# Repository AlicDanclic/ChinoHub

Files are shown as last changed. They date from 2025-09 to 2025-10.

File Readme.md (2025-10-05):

# ChinoHub

由于经常的插拔,导致我的电脑只有一个USB可以用来,是的只有一个了,所以我有必要做一个Hub,之前做一个支持2.0的KVM,但是突然有一个大电流以及没有做外壳导致这个hub由很大的问题,以及,该KVM的设计上仍有很多问题.例如大电流过滤问题,没有静电保护,同时该作为一个DIY项目,他似乎缺少了很多交互性,在参考了[TypeC转HDMI视频输出模块 - 立创开源硬件平台](https://oshwhub.com/lemon_wifi/CS5265)以及[高速USB3.0共享器 四进四出选择 HUB+切换器 - 立创开源硬件平台](https://oshwhub.com/aknice/vl822-ch484m-si-jin-si-chu-usb3-0-hub),我决定开启一个高速PCB的设计项目,ChinoHub,是的,我喜欢看点兔,我最喜欢智乃了❤.

## 项目架构

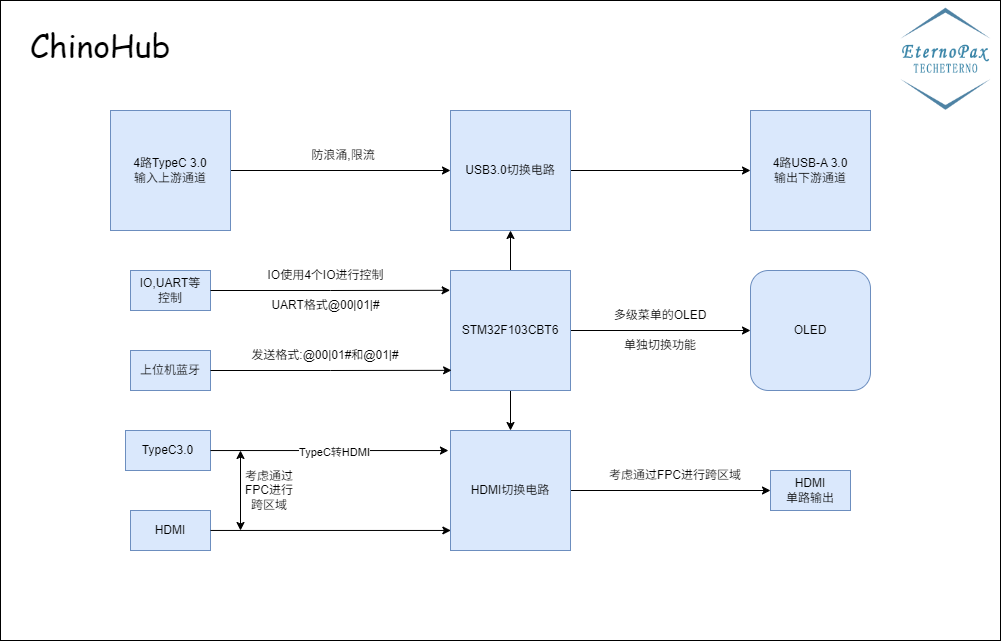
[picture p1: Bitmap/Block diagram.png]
系统框图


## 硬件设计注意事项

> 本设计大量用到USB3.0,布线时要遵循高速和差分.

在设计中,我们用到的电源为5V的输入,3.3V和1.0V的输入,(原理图中有1.8V那是芯片自己产生的,在本项目中没用),考虑最坏情况下,对应的峰值电流为:

| 电压域 | 最坏情况峰值电流 | 关键贡献者 |
| :--- | :--- | :--- |
| **3.3V** | **538 mA** | VL822(300mA) + CS5265(150mA) + STM32(75mA) |
| **5V** | **600 mA** | LP3220输入(400mA) + CS5265(200mA) |
| **1.0V** | **200 mA** | VL822(150mA) + CS5265(50mA) |

所以考虑1.5倍富裕度,这里选择了MP2122A,输出为2A的二路DCDC.同时STM32由LDO单独供电防止纹波问题.计算公式可以参看Datasheet,为:$0.6V \times(1+\frac{R_1}{R_2})$

在设计时候用了一个防浪涌的模拟电路,对于多电源可能同时输入,效果还是不错的.

## 软件烧录

## 使用指南

### 日志

2025.10.4完成原理图绘制,等待审查

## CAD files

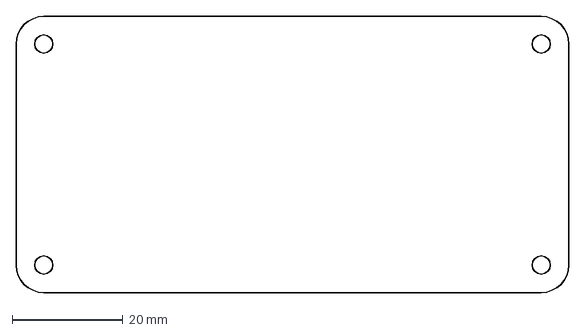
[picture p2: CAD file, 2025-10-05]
3D/plate_Cut.dxf
100.0 x 50.0 mm

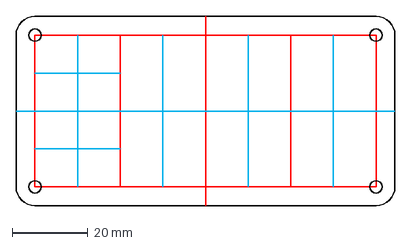
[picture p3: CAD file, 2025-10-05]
3D/plate.dxf
100.0 x 50.0 mm

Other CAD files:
3D/plate.dwg

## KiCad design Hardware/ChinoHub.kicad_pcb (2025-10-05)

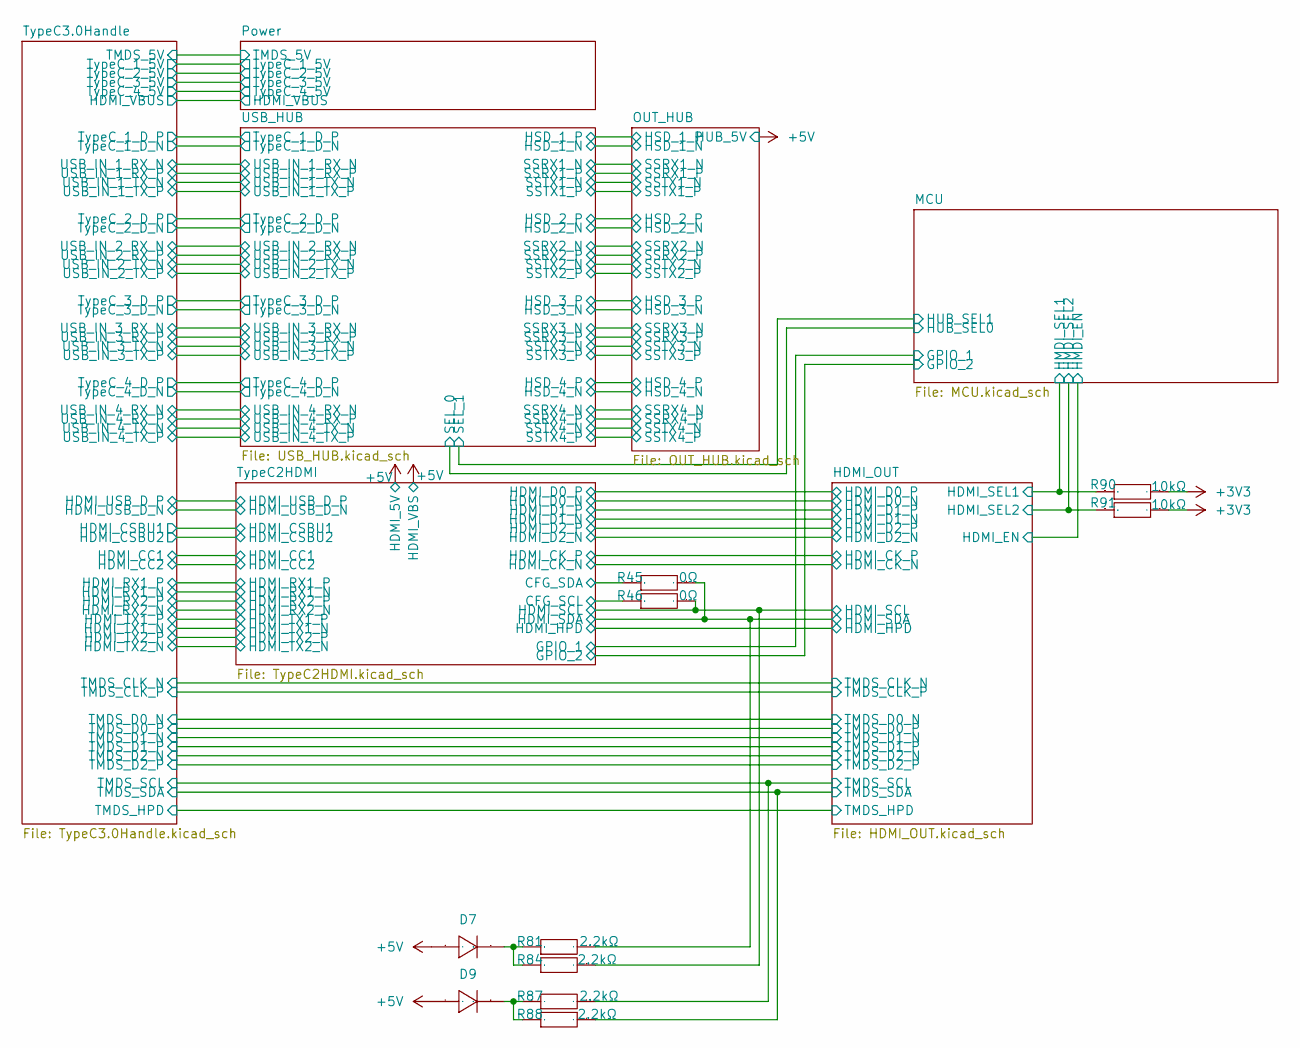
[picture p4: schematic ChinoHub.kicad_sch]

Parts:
D7, D9: SOD-323F_L1.7-W1.3-LS2.5-R-RD; Manufacturer Part 1N4148WSL; LCSC Part Name 1N4148WSL
R45, R46: 0Ω; R0603; Manufacturer Part 0603WAF1002T5E; LCSC Part Name 厚膜电阻 10kΩ ±1% 100mW
R81, R84, R87, R88: 2.2kΩ; R0603; Manufacturer Part 0603WAF1002T5E; LCSC Part Name 厚膜电阻 10kΩ ±1% 100mW
R90, R91: 10kΩ; R0603; Manufacturer Part 0603WAF1002T5E; LCSC Part Name 厚膜电阻 10kΩ ±1% 100mW

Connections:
+3V3: R90.2, R91.2; also elsewhere on the board
+5V: D7.2, D9.2; also elsewhere on the board
/HDMI_OUT/HDMI_SCL: R46.2, R84.2; also elsewhere on the board
/HDMI_OUT/HDMI_SDA: R45.2, R81.2; also elsewhere on the board
/HDMI_OUT/TMDS_SCL: R87.2; also elsewhere on the board
/HDMI_OUT/TMDS_SDA: R88.2; also elsewhere on the board
/MCU/HDMI_SEL1: R90.1; also elsewhere on the board
/MCU/HDMI_SEL2: R91.1; also elsewhere on the board
/TypeC2HDMI/CFG_SCL: R46.1; also elsewhere on the board
/TypeC2HDMI/CFG_SDA: R45.1; also elsewhere on the board
unnamed: D7.1, R81.1, R84.1
unnamed: D9.1, R87.1, R88.1

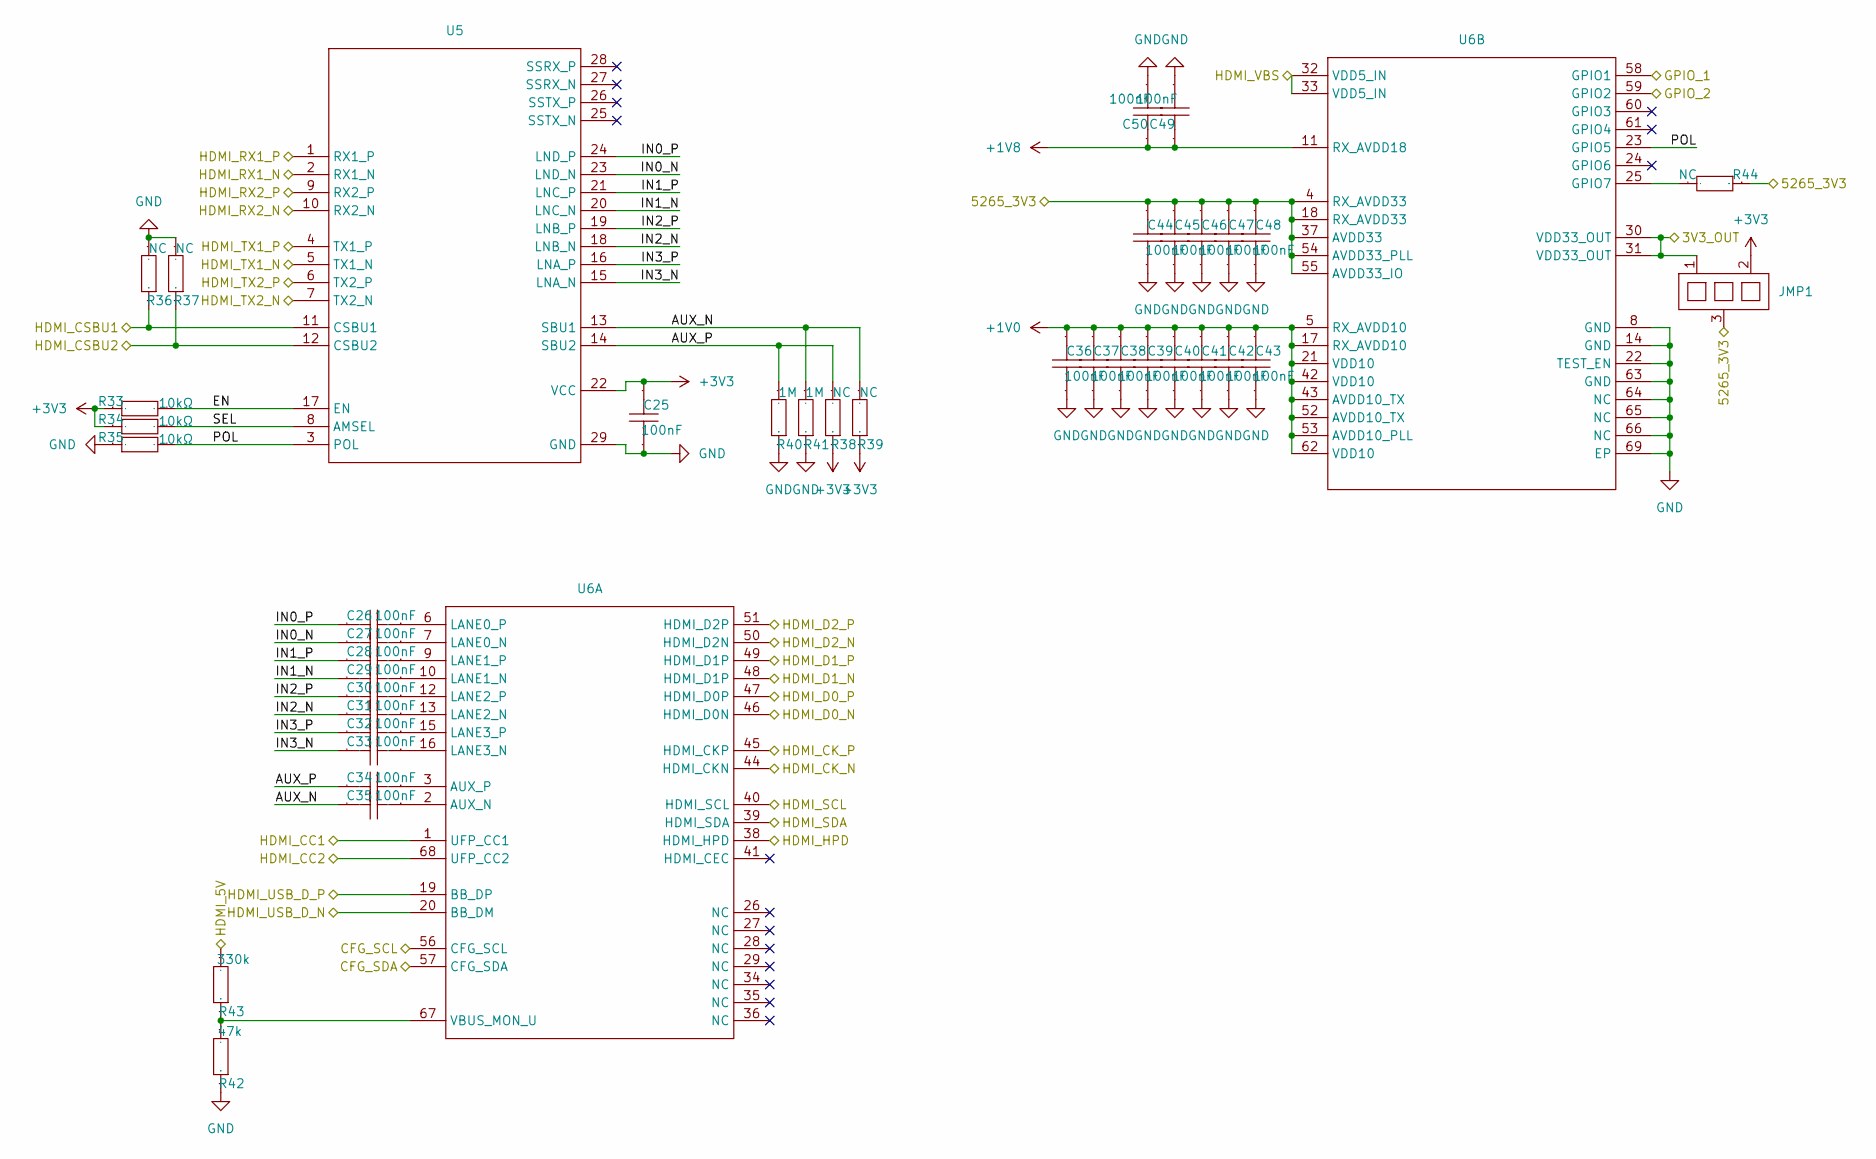
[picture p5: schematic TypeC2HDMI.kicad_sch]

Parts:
C25, C26, C27, C28, C29, C30, C31, C32, C33, C34, C35, C36, C37, C38, C39, C40, C41, C42, C43, C44, C45, C46, C47, C48, C49, C50: 100nF; C0603; Manufacturer Part CL10A105KB8NNNC; LCSC Part Name 1uF ±10% 50V
JMP1: JUMP0603
R33, R34, R35: 10kΩ; R0603; Manufacturer Part 0603WAF1002T5E; LCSC Part Name 厚膜电阻 10kΩ ±1% 100mW
R36, R37, R38, R39, R44: NC; R0603; Manufacturer Part 0603WAF1002T5E; LCSC Part Name 厚膜电阻 10kΩ ±1% 100mW
R40, R41: 1M; R0603; Manufacturer Part 0603WAF1002T5E; LCSC Part Name 厚膜电阻 10kΩ ±1% 100mW
R42: 47k; R0603; Manufacturer Part 0603WAF1002T5E; LCSC Part Name 厚膜电阻 10kΩ ±1% 100mW
R43: 330k; R0603; Manufacturer Part 0603WAF1002T5E; LCSC Part Name 厚膜电阻 10kΩ ±1% 100mW
U5: MQFN-28_L4.5-W3.5-P0.40-BL-EP
U6: QFN-68

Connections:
+1V0: C36.2, C37.2, C38.2, C39.2, C40.2, C41.2, C42.2, C43.2, U6.5 (RX_AVDD10), U6.17 (RX_AVDD10), U6.21 (VDD10), U6.42 (VDD10), U6.43 (AVDD10_TX), U6.52 (AVDD10_TX), U6.53 (AVDD10_PLL), U6.62 (VDD10); also elsewhere on the board
+1V8: C49.2, C50.2, U6.11 (RX_AVDD18)
+3V3: C25.2, JMP1.2, R33.1, R34.1, R38.1, R39.1, U5.22 (VCC); also elsewhere on the board
+5V: R43.2, U6.32 (VDD5_IN), U6.33 (VDD5_IN); also elsewhere on the board
/HDMI_OUT/HDMI_CK_N: U6.44 (HDMI_CKN); also elsewhere on the board
/HDMI_OUT/HDMI_CK_P: U6.45 (HDMI_CKP); also elsewhere on the board
/HDMI_OUT/HDMI_D0_N: U6.46 (HDMI_D0N); also elsewhere on the board
/HDMI_OUT/HDMI_D0_P: U6.47 (HDMI_D0P); also elsewhere on the board
/HDMI_OUT/HDMI_D1_N: U6.48 (HDMI_D1P); also elsewhere on the board
/HDMI_OUT/HDMI_D1_P: U6.49 (HDMI_D1P); also elsewhere on the board
/HDMI_OUT/HDMI_D2_N: U6.50 (HDMI_D2N); also elsewhere on the board
/HDMI_OUT/HDMI_D2_P: U6.51 (HDMI_D2P); also elsewhere on the board
/HDMI_OUT/HDMI_HPD: U6.38 (HDMI_HPD); also elsewhere on the board
/HDMI_OUT/HDMI_SCL: U6.40 (HDMI_SCL); also elsewhere on the board
/HDMI_OUT/HDMI_SDA: U6.39 (HDMI_SDA); also elsewhere on the board
/MCU/GPIO_1: U6.58 (GPIO1); also elsewhere on the board
/MCU/GPIO_2: U6.59 (GPIO2); also elsewhere on the board
/TypeC2HDMI/3V3_OUT: JMP1.1, U6.30 (VDD33_OUT), U6.31 (VDD33_OUT)
/TypeC2HDMI/5265_3V3: C44.2, C45.2, C46.2, C47.2, C48.2, JMP1.3, R44.1, U6.4 (RX_AVDD33), U6.18 (RX_AVDD33), U6.37 (AVDD33), U6.54 (AVDD33_PLL), U6.55 (AVDD33_IO)
/TypeC2HDMI/AUX_N: C35.2, R39.2, R41.2, U5.13 (SBU1)
/TypeC2HDMI/AUX_P: C34.2, R38.2, R40.2, U5.14 (SBU2)
/TypeC2HDMI/CFG_SCL: U6.56 (CFG_SCL); also elsewhere on the board
/TypeC2HDMI/CFG_SDA: U6.57 (CFG_SDA); also elsewhere on the board
/TypeC2HDMI/EN: R33.2, U5.17 (EN)
/TypeC2HDMI/HDMI_CC1: U6.1 (UFP_CC1); also elsewhere on the board
/TypeC2HDMI/HDMI_CC2: U6.68 (UFP_CC2); also elsewhere on the board
/TypeC2HDMI/HDMI_CSBU1: R36.1, U5.11 (CSBU1); also elsewhere on the board
/TypeC2HDMI/HDMI_CSBU2: R37.1, U5.12 (CSBU2); also elsewhere on the board
/TypeC2HDMI/HDMI_RX1_N: U5.2 (RX1_N); also elsewhere on the board
/TypeC2HDMI/HDMI_RX1_P: U5.1 (RX1_P); also elsewhere on the board
/TypeC2HDMI/HDMI_RX2_N: U5.10 (RX2_N); also elsewhere on the board
/TypeC2HDMI/HDMI_RX2_P: U5.9 (RX2_P); also elsewhere on the board
/TypeC2HDMI/HDMI_TX1_N: U5.5 (TX1_N); also elsewhere on the board
/TypeC2HDMI/HDMI_TX1_P: U5.4 (TX1_P); also elsewhere on the board
/TypeC2HDMI/HDMI_TX2_N: U5.7 (TX2_N); also elsewhere on the board
/TypeC2HDMI/HDMI_TX2_P: U5.6 (TX2_P); also elsewhere on the board
/TypeC2HDMI/HDMI_USB_D_N: U6.20 (BB_DM); also elsewhere on the board
/TypeC2HDMI/HDMI_USB_D_P: U6.19 (BB_DP); also elsewhere on the board
/TypeC2HDMI/IN0_N: C27.2, U5.23 (LND_N)
/TypeC2HDMI/IN0_P: C26.2, U5.24 (LND_P)
/TypeC2HDMI/IN1_N: C29.2, U5.20 (LNC_N)
/TypeC2HDMI/IN1_P: C28.2, U5.21 (LNC_P)
/TypeC2HDMI/IN2_N: C31.2, U5.18 (LNB_N)
/TypeC2HDMI/IN2_P: C30.2, U5.19 (LNB_P)
/TypeC2HDMI/IN3_N: C33.2, U5.15 (LNA_N)
/TypeC2HDMI/IN3_P: C32.2, U5.16 (LNA_P)
/TypeC2HDMI/POL: R35.2, U5.3 (POL), U6.23 (GPIO5)
/TypeC2HDMI/SEL: R34.2, U5.8 (AMSEL)
GND: C25.1, C36.1, C37.1, C38.1, C39.1, C40.1, C41.1, C42.1, C43.1, C44.1, C45.1, C46.1, C47.1, C48.1, C49.1, C50.1, R35.1, R36.2, R37.2, R40.1, R41.1, R42.1, U5.29 (GND), U6.8 (GND), U6.14 (GND), U6.22 (TEST_EN), U6.63 (GND), U6.64 (NC), U6.65 (NC), U6.66 (NC), U6.69 (EP); also elsewhere on the board
unnamed: C35.1, U6.2 (AUX_N)
unnamed: C34.1, U6.3 (AUX_P)
unnamed: C27.1, U6.7 (LANE0_N)
unnamed: C26.1, U6.6 (LANE0_P)
unnamed: C29.1, U6.10 (LANE1_N)
unnamed: C28.1, U6.9 (LANE1_P)
unnamed: C31.1, U6.13 (LANE2_N)
unnamed: C30.1, U6.12 (LANE2_P)
unnamed: C33.1, U6.16 (LANE3_N)
unnamed: C32.1, U6.15 (LANE3_P)
unnamed: R42.2, R43.1, U6.67 (VBUS_MON_U)
unnamed: R44.2, U6.25 (GPIO7)

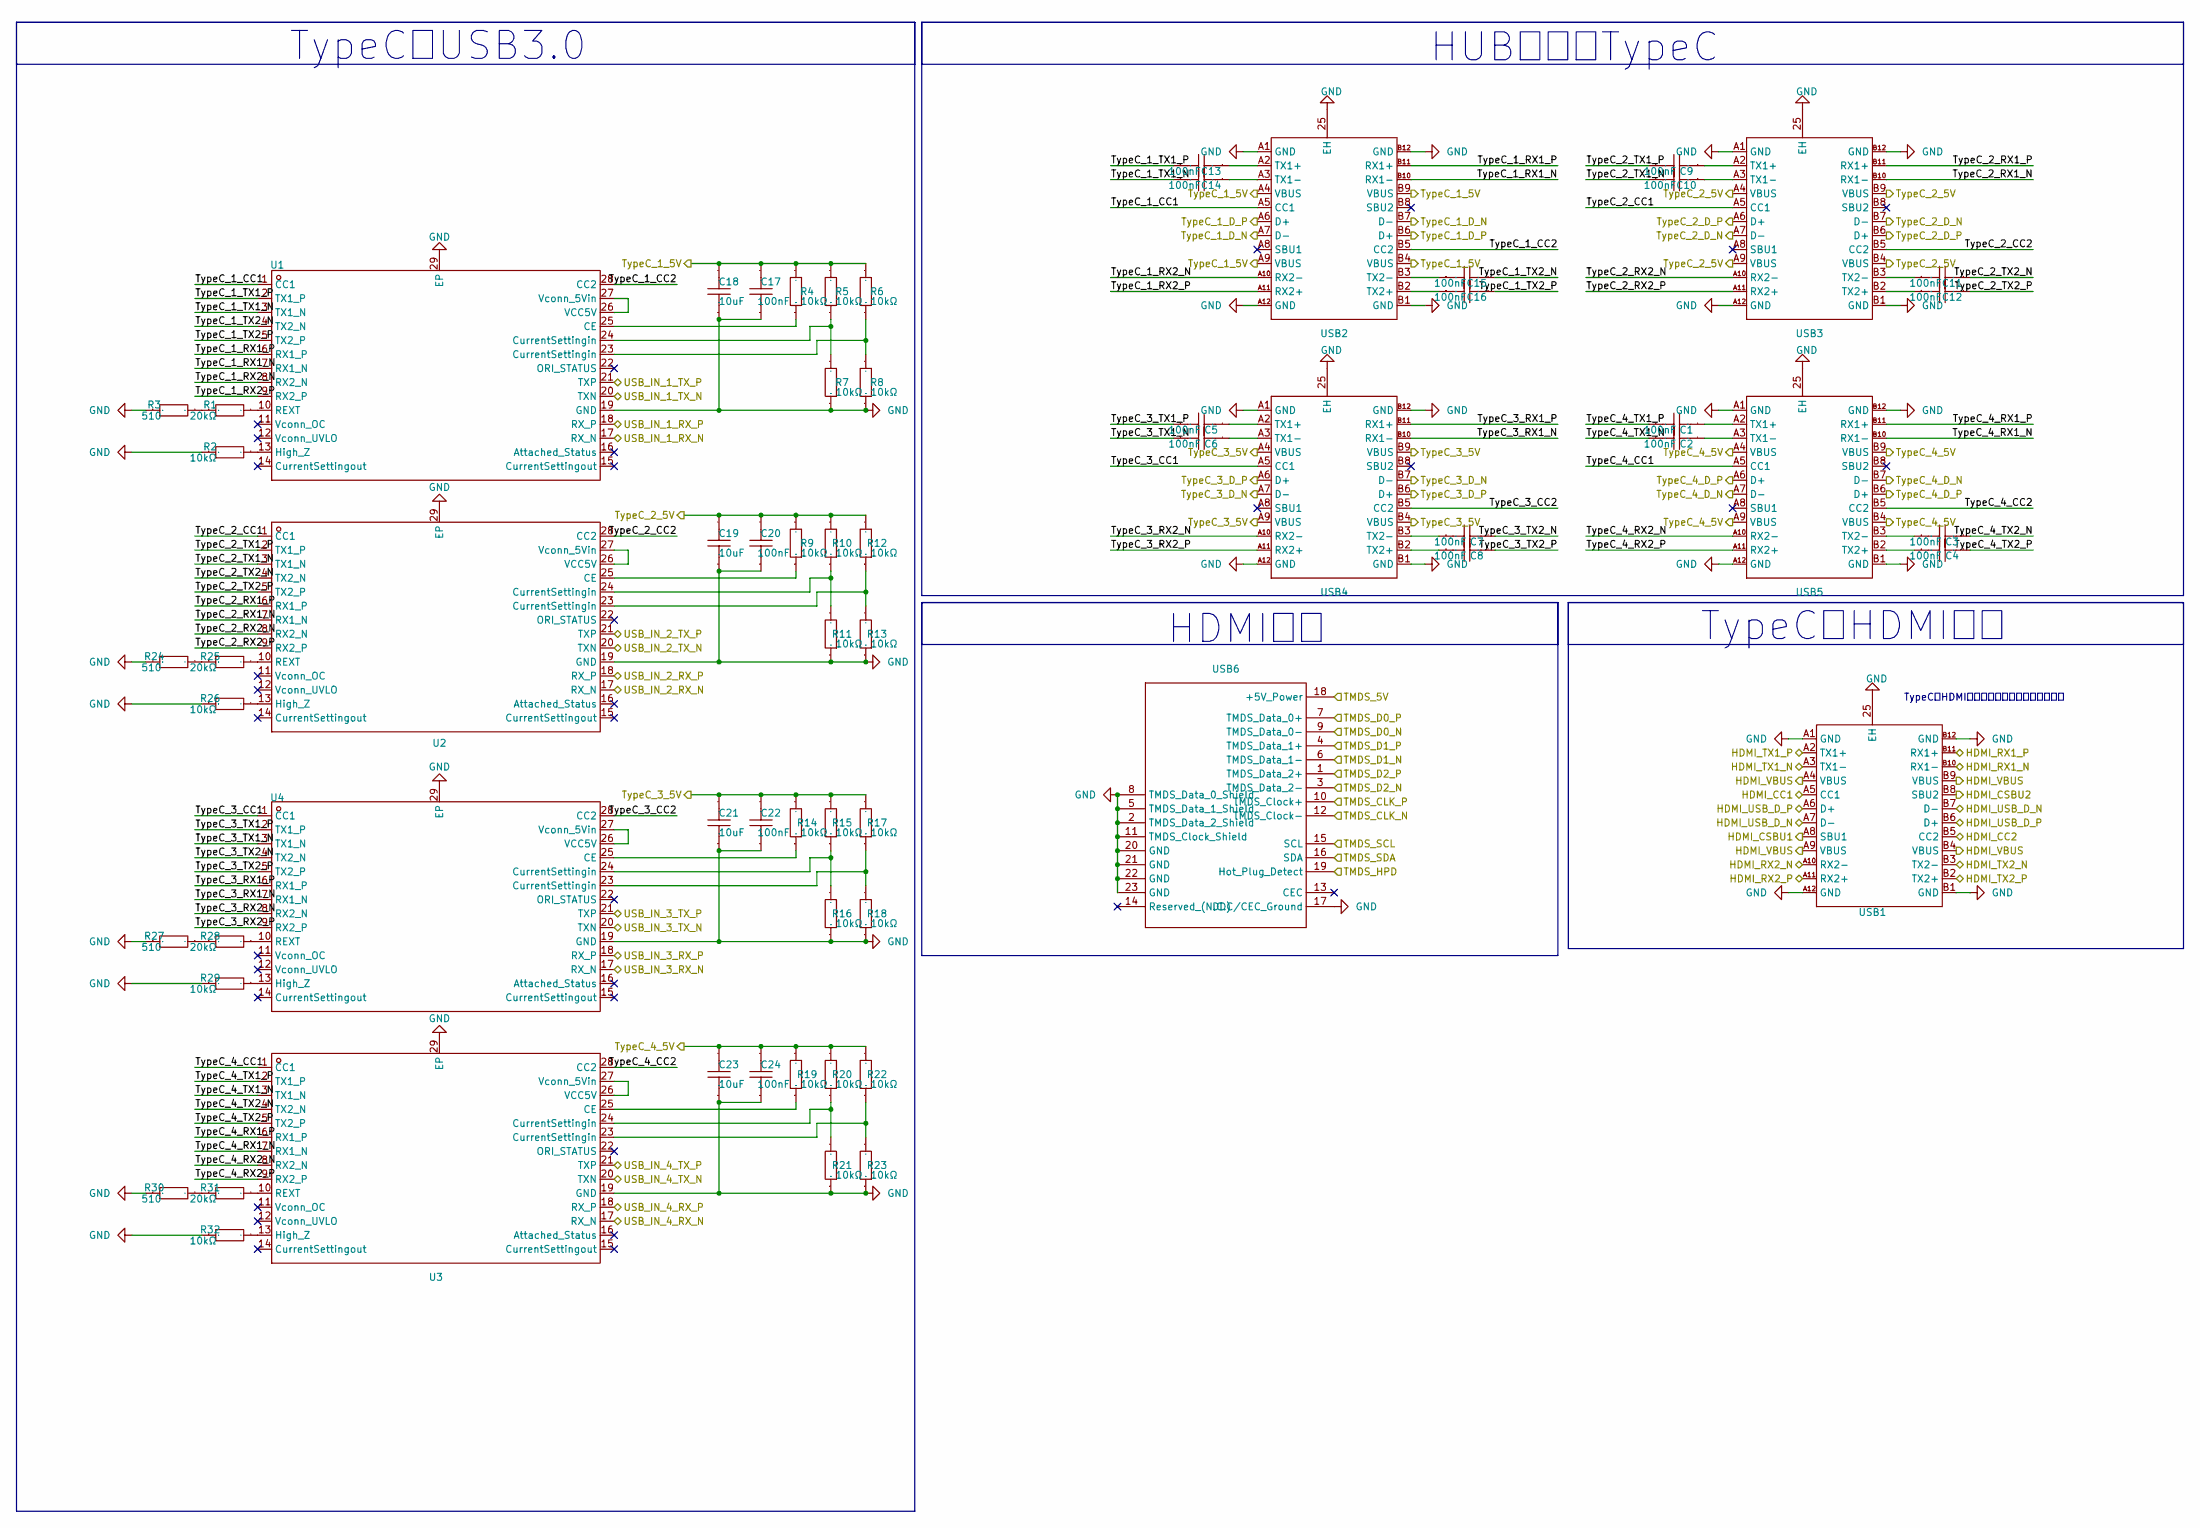
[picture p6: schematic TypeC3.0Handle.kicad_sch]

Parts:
C1, C2, C3, C4, C5, C6, C7, C8, C9, C10, C11, C12, C13, C14, C15, C16, C17, C20, C22, C24: 100nF; C0603; Manufacturer Part CL10A105KB8NNNC; LCSC Part Name 1uF ±10% 50V
C18, C19, C21, C23: 10uF; C0603; Manufacturer Part CL10A105KB8NNNC; LCSC Part Name 1uF ±10% 50V
R1, R25, R28, R31: 20kΩ; R0603; Manufacturer Part 0603WAF1002T5E; LCSC Part Name 厚膜电阻 10kΩ ±1% 100mW
R2, R4, R5, R6, R7, R8, R9, R10, R11, R12, R13, R14, R15, R16, R17, R18, R19, R20, R21, R22, R23, R26, R29, R32: 10kΩ; R0603; Manufacturer Part 0603WAF1002T5E; LCSC Part Name 厚膜电阻 10kΩ ±1% 100mW
R3, R24, R27, R30: 510; R0603; Manufacturer Part 0603WAF1002T5E; LCSC Part Name 厚膜电阻 10kΩ ±1% 100mW
U1, U2, U3, U4: MQFN-28_L4.5-W3.5-P0.40-BL-EP; Manufacturer Part VL160; LCSC Part Name VL160
USB1, USB2, USB3, USB4, USB5: TYPE-C-SMD_TYPE-C-24P-QCHT; Manufacturer Part TYPE-C 24P QCHT; LCSC Part Name Type-C 母 卧贴
USB6: HDMI-SMD_HDMI-001S; Manufacturer Part HDMI-001S; LCSC Part Name HDMI-001S

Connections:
/HDMI_OUT/TMDS_CLK_N: USB6.12 (TMDS_Clock-); also elsewhere on the board
/HDMI_OUT/TMDS_CLK_P: USB6.10 (TMDS_Clock+); also elsewhere on the board
/HDMI_OUT/TMDS_D0_N: USB6.9 (TMDS_Data_0-); also elsewhere on the board
/HDMI_OUT/TMDS_D0_P: USB6.7 (TMDS_Data_0+); also elsewhere on the board
/HDMI_OUT/TMDS_D1_N: USB6.6 (TMDS_Data_1-); also elsewhere on the board
/HDMI_OUT/TMDS_D1_P: USB6.4 (TMDS_Data_1+); also elsewhere on the board
/HDMI_OUT/TMDS_D2_N: USB6.3 (TMDS_Data_2-); also elsewhere on the board
/HDMI_OUT/TMDS_D2_P: USB6.1 (TMDS_Data_2+); also elsewhere on the board
/HDMI_OUT/TMDS_HPD: USB6.19 (Hot_Plug_Detect); also elsewhere on the board
/HDMI_OUT/TMDS_SCL: USB6.15 (SCL); also elsewhere on the board
/HDMI_OUT/TMDS_SDA: USB6.16 (SDA); also elsewhere on the board
/Power/HDMI_VBUS: USB1.A4 (VBUS), USB1.A9 (VBUS), USB1.B4 (VBUS), USB1.B9 (VBUS); also elsewhere on the board
/Power/TMDS_5V: USB6.18 (+5V_Power); also elsewhere on the board
/Power/TypeC_1_5V: C17.2, C18.2, R4.2, R5.2, R6.2, USB2.A4 (VBUS), USB2.A9 (VBUS), USB2.B4 (VBUS), USB2.B9 (VBUS); also elsewhere on the board
/Power/TypeC_2_5V: C19.2, C20.2, R9.2, R10.2, R12.2, USB3.A4 (VBUS), USB3.A9 (VBUS), USB3.B4 (VBUS), USB3.B9 (VBUS); also elsewhere on the board
/Power/TypeC_3_5V: C21.2, C22.2, R14.2, R15.2, R17.2, USB4.A4 (VBUS), USB4.A9 (VBUS), USB4.B4 (VBUS), USB4.B9 (VBUS); also elsewhere on the board
/Power/TypeC_4_5V: C23.2, C24.2, R19.2, R20.2, R22.2, USB5.A4 (VBUS), USB5.A9 (VBUS), USB5.B4 (VBUS), USB5.B9 (VBUS); also elsewhere on the board
/TypeC2HDMI/HDMI_CC1: USB1.A5 (CC1); also elsewhere on the board
/TypeC2HDMI/HDMI_CC2: USB1.B5 (CC2); also elsewhere on the board
/TypeC2HDMI/HDMI_CSBU1: USB1.A8 (SBU1); also elsewhere on the board
/TypeC2HDMI/HDMI_CSBU2: USB1.B8 (SBU2); also elsewhere on the board
/TypeC2HDMI/HDMI_RX1_N: USB1.B10 (RX1-); also elsewhere on the board
/TypeC2HDMI/HDMI_RX1_P: USB1.B11 (RX1+); also elsewhere on the board
/TypeC2HDMI/HDMI_RX2_N: USB1.A10 (RX2-); also elsewhere on the board
/TypeC2HDMI/HDMI_RX2_P: USB1.A11 (RX2+); also elsewhere on the board
/TypeC2HDMI/HDMI_TX1_N: USB1.A3 (TX1-); also elsewhere on the board
/TypeC2HDMI/HDMI_TX1_P: USB1.A2 (TX1+); also elsewhere on the board
/TypeC2HDMI/HDMI_TX2_N: USB1.B3 (TX2-); also elsewhere on the board
/TypeC2HDMI/HDMI_TX2_P: USB1.B2 (TX2+); also elsewhere on the board
/TypeC2HDMI/HDMI_USB_D_N: USB1.A7 (D-), USB1.B7 (D-); also elsewhere on the board
/TypeC2HDMI/HDMI_USB_D_P: USB1.A6 (D+), USB1.B6 (D+); also elsewhere on the board
/TypeC3.0Handle/TypeC_1_CC1: U1.1 (CC1), USB2.A5 (CC1)
/TypeC3.0Handle/TypeC_1_CC2: U1.28 (CC2), USB2.B5 (CC2)
/TypeC3.0Handle/TypeC_1_D_N: USB2.A7 (D-), USB2.B7 (D-); also elsewhere on the board
/TypeC3.0Handle/TypeC_1_D_P: USB2.A6 (D+), USB2.B6 (D+); also elsewhere on the board
/TypeC3.0Handle/TypeC_1_RX1_N: U1.7 (RX1_N), USB2.B10 (RX1-)
/TypeC3.0Handle/TypeC_1_RX1_P: U1.6 (RX1_P), USB2.B11 (RX1+)
/TypeC3.0Handle/TypeC_1_RX2_N: U1.8 (RX2_N), USB2.A10 (RX2-)
/TypeC3.0Handle/TypeC_1_RX2_P: U1.9 (RX2_P), USB2.A11 (RX2+)
/TypeC3.0Handle/TypeC_1_TX1_N: C14.1, U1.3 (TX1_N)
/TypeC3.0Handle/TypeC_1_TX1_P: C13.1, U1.2 (TX1_P)
/TypeC3.0Handle/TypeC_1_TX2_N: C15.2, U1.4 (TX2_N)
/TypeC3.0Handle/TypeC_1_TX2_P: C16.2, U1.5 (TX2_P)
/TypeC3.0Handle/TypeC_2_CC1: U2.1 (CC1), USB3.A5 (CC1)
/TypeC3.0Handle/TypeC_2_CC2: U2.28 (CC2), USB3.B5 (CC2)
/TypeC3.0Handle/TypeC_2_D_N: USB3.A7 (D-), USB3.B7 (D-); also elsewhere on the board
/TypeC3.0Handle/TypeC_2_D_P: USB3.A6 (D+), USB3.B6 (D+); also elsewhere on the board
/TypeC3.0Handle/TypeC_2_RX1_N: U2.7 (RX1_N), USB3.B10 (RX1-)
/TypeC3.0Handle/TypeC_2_RX1_P: U2.6 (RX1_P), USB3.B11 (RX1+)
/TypeC3.0Handle/TypeC_2_RX2_N: U2.8 (RX2_N), USB3.A10 (RX2-)
/TypeC3.0Handle/TypeC_2_RX2_P: U2.9 (RX2_P), USB3.A11 (RX2+)
/TypeC3.0Handle/TypeC_2_TX1_N: C10.1, U2.3 (TX1_N)
/TypeC3.0Handle/TypeC_2_TX1_P: C9.1, U2.2 (TX1_P)
/TypeC3.0Handle/TypeC_2_TX2_N: C11.2, U2.4 (TX2_N)
/TypeC3.0Handle/TypeC_2_TX2_P: C12.2, U2.5 (TX2_P)
/TypeC3.0Handle/TypeC_3_CC1: U4.1 (CC1), USB4.A5 (CC1)
/TypeC3.0Handle/TypeC_3_CC2: U4.28 (CC2), USB4.B5 (CC2)
/TypeC3.0Handle/TypeC_3_D_N: USB4.A7 (D-), USB4.B7 (D-); also elsewhere on the board
/TypeC3.0Handle/TypeC_3_D_P: USB4.A6 (D+), USB4.B6 (D+); also elsewhere on the board
/TypeC3.0Handle/TypeC_3_RX1_N: U4.7 (RX1_N), USB4.B10 (RX1-)
/TypeC3.0Handle/TypeC_3_RX1_P: U4.6 (RX1_P), USB4.B11 (RX1+)
/TypeC3.0Handle/TypeC_3_RX2_N: U4.8 (RX2_N), USB4.A10 (RX2-)
/TypeC3.0Handle/TypeC_3_RX2_P: U4.9 (RX2_P), USB4.A11 (RX2+)
/TypeC3.0Handle/TypeC_3_TX1_N: C6.1, U4.3 (TX1_N)
/TypeC3.0Handle/TypeC_3_TX1_P: C5.1, U4.2 (TX1_P)
/TypeC3.0Handle/TypeC_3_TX2_N: C7.2, U4.4 (TX2_N)
/TypeC3.0Handle/TypeC_3_TX2_P: C8.2, U4.5 (TX2_P)
/TypeC3.0Handle/TypeC_4_CC1: U3.1 (CC1), USB5.A5 (CC1)
/TypeC3.0Handle/TypeC_4_CC2: U3.28 (CC2), USB5.B5 (CC2)
/TypeC3.0Handle/TypeC_4_D_N: USB5.A7 (D-), USB5.B7 (D-); also elsewhere on the board
/TypeC3.0Handle/TypeC_4_D_P: USB5.A6 (D+), USB5.B6 (D+); also elsewhere on the board
/TypeC3.0Handle/TypeC_4_RX1_N: U3.7 (RX1_N), USB5.B10 (RX1-)
/TypeC3.0Handle/TypeC_4_RX1_P: U3.6 (RX1_P), USB5.B11 (RX1+)
/TypeC3.0Handle/TypeC_4_RX2_N: U3.8 (RX2_N), USB5.A10 (RX2-)
/TypeC3.0Handle/TypeC_4_RX2_P: U3.9 (RX2_P), USB5.A11 (RX2+)
/TypeC3.0Handle/TypeC_4_TX1_N: C2.1, U3.3 (TX1_N)
/TypeC3.0Handle/TypeC_4_TX1_P: C1.1, U3.2 (TX1_P)
/TypeC3.0Handle/TypeC_4_TX2_N: C3.2, U3.4 (TX2_N)
/TypeC3.0Handle/TypeC_4_TX2_P: C4.2, U3.5 (TX2_P)
/TypeC3.0Handle/USB_IN_1_RX_N: U1.17 (RX_N); also elsewhere on the board
/TypeC3.0Handle/USB_IN_1_RX_P: U1.18 (RX_P); also elsewhere on the board
/TypeC3.0Handle/USB_IN_1_TX_N: U1.20 (TXN); also elsewhere on the board
/TypeC3.0Handle/USB_IN_1_TX_P: U1.21 (TXP); also elsewhere on the board
/TypeC3.0Handle/USB_IN_2_RX_N: U2.17 (RX_N); also elsewhere on the board
/TypeC3.0Handle/USB_IN_2_RX_P: U2.18 (RX_P); also elsewhere on the board
/TypeC3.0Handle/USB_IN_2_TX_N: U2.20 (TXN); also elsewhere on the board
/TypeC3.0Handle/USB_IN_2_TX_P: U2.21 (TXP); also elsewhere on the board
/TypeC3.0Handle/USB_IN_3_RX_N: U4.17 (RX_N); also elsewhere on the board
/TypeC3.0Handle/USB_IN_3_RX_P: U4.18 (RX_P); also elsewhere on the board
/TypeC3.0Handle/USB_IN_3_TX_N: U4.20 (TXN); also elsewhere on the board
/TypeC3.0Handle/USB_IN_3_TX_P: U4.21 (TXP); also elsewhere on the board
/TypeC3.0Handle/USB_IN_4_RX_N: U3.17 (RX_N); also elsewhere on the board
/TypeC3.0Handle/USB_IN_4_RX_P: U3.18 (RX_P); also elsewhere on the board
/TypeC3.0Handle/USB_IN_4_TX_N: U3.20 (TXN); also elsewhere on the board
/TypeC3.0Handle/USB_IN_4_TX_P: U3.21 (TXP); also elsewhere on the board
GND: C17.1, C18.1, C19.1, C20.1, C21.1, C22.1, C23.1, C24.1, R2.1, R3.1, R7.1, R8.1, R11.1, R13.1, R16.1, R18.1, R21.1, R23.1, R24.1, R26.1, R27.1, R29.1, R30.1, R32.1, U1.19 (GND), U1.29 (EP), U2.19 (GND), U2.29 (EP), U3.19 (GND), U3.29 (EP), U4.19 (GND), U4.29 (EP), USB1.25 (EH), USB1.A1 (GND), USB1.A12 (GND), USB1.B1 (GND), USB1.B12 (GND), USB2.25 (EH), USB2.A1 (GND), USB2.A12 (GND), USB2.B1 (GND), USB2.B12 (GND), USB3.25 (EH), USB3.A1 (GND), USB3.A12 (GND), USB3.B1 (GND), USB3.B12 (GND), USB4.25 (EH), USB4.A1 (GND), USB4.A12 (GND), USB4.B1 (GND), USB4.B12 (GND), USB5.25 (EH), USB5.A1 (GND), USB5.A12 (GND), USB5.B1 (GND), USB5.B12 (GND), USB6.2 (TMDS_Data_2_Shield), USB6.5 (TMDS_Data_1_Shield), USB6.8 (TMDS_Data_0_Shield), USB6.11 (TMDS_Clock_Shield), USB6.17 (DDC/CEC_Ground), USB6.20 (GND), USB6.21 (GND), USB6.22 (GND), USB6.23 (GND); also elsewhere on the board
unnamed: R1.1, R3.2
unnamed: R5.1, R7.2, U1.24 (CurrentSettingin)
unnamed: R6.1, R8.2, U1.23 (CurrentSettingin)
unnamed: R10.1, R11.2, U2.24 (CurrentSettingin)
unnamed: R12.1, R13.2, U2.23 (CurrentSettingin)
unnamed: R15.1, R16.2, U4.24 (CurrentSettingin)
unnamed: R17.1, R18.2, U4.23 (CurrentSettingin)
unnamed: R20.1, R21.2, U3.24 (CurrentSettingin)
unnamed: R22.1, R23.2, U3.23 (CurrentSettingin)
unnamed: R24.2, R25.1
unnamed: R27.2, R28.1
unnamed: R30.2, R31.1
unnamed: R4.1, U1.25 (CE)
unnamed: R2.2, U1.13 (High_Z)
unnamed: R1.2, U1.10 (REXT)
unnamed: U1.26 (VCC5V), U1.27 (Vconn_5Vin)
unnamed: R9.1, U2.25 (CE)
unnamed: R26.2, U2.13 (High_Z)
unnamed: R25.2, U2.10 (REXT)
unnamed: U2.26 (VCC5V), U2.27 (Vconn_5Vin)
unnamed: R19.1, U3.25 (CE)
unnamed: R32.2, U3.13 (High_Z)
unnamed: R31.2, U3.10 (REXT)
unnamed: U3.26 (VCC5V), U3.27 (Vconn_5Vin)
unnamed: R14.1, U4.25 (CE)
unnamed: R29.2, U4.13 (High_Z)
unnamed: R28.2, U4.10 (REXT)
unnamed: U4.26 (VCC5V), U4.27 (Vconn_5Vin)
unnamed: C13.2, USB2.A2 (TX1+)
unnamed: C14.2, USB2.A3 (TX1-)
unnamed: C16.1, USB2.B2 (TX2+)
unnamed: C15.1, USB2.B3 (TX2-)
unnamed: C9.2, USB3.A2 (TX1+)
unnamed: C10.2, USB3.A3 (TX1-)
unnamed: C12.1, USB3.B2 (TX2+)
unnamed: C11.1, USB3.B3 (TX2-)
unnamed: C5.2, USB4.A2 (TX1+)
unnamed: C6.2, USB4.A3 (TX1-)
unnamed: C8.1, USB4.B2 (TX2+)
unnamed: C7.1, USB4.B3 (TX2-)
unnamed: C1.2, USB5.A2 (TX1+)
unnamed: C2.2, USB5.A3 (TX1-)
unnamed: C4.1, USB5.B2 (TX2+)
unnamed: C3.1, USB5.B3 (TX2-)

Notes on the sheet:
HUB的上游TypeC
TypeC转HDMI不进行预处理后续处理较为麻烦
HDMI输入
TypeC转USB3.0
TypeC转HDMI输入

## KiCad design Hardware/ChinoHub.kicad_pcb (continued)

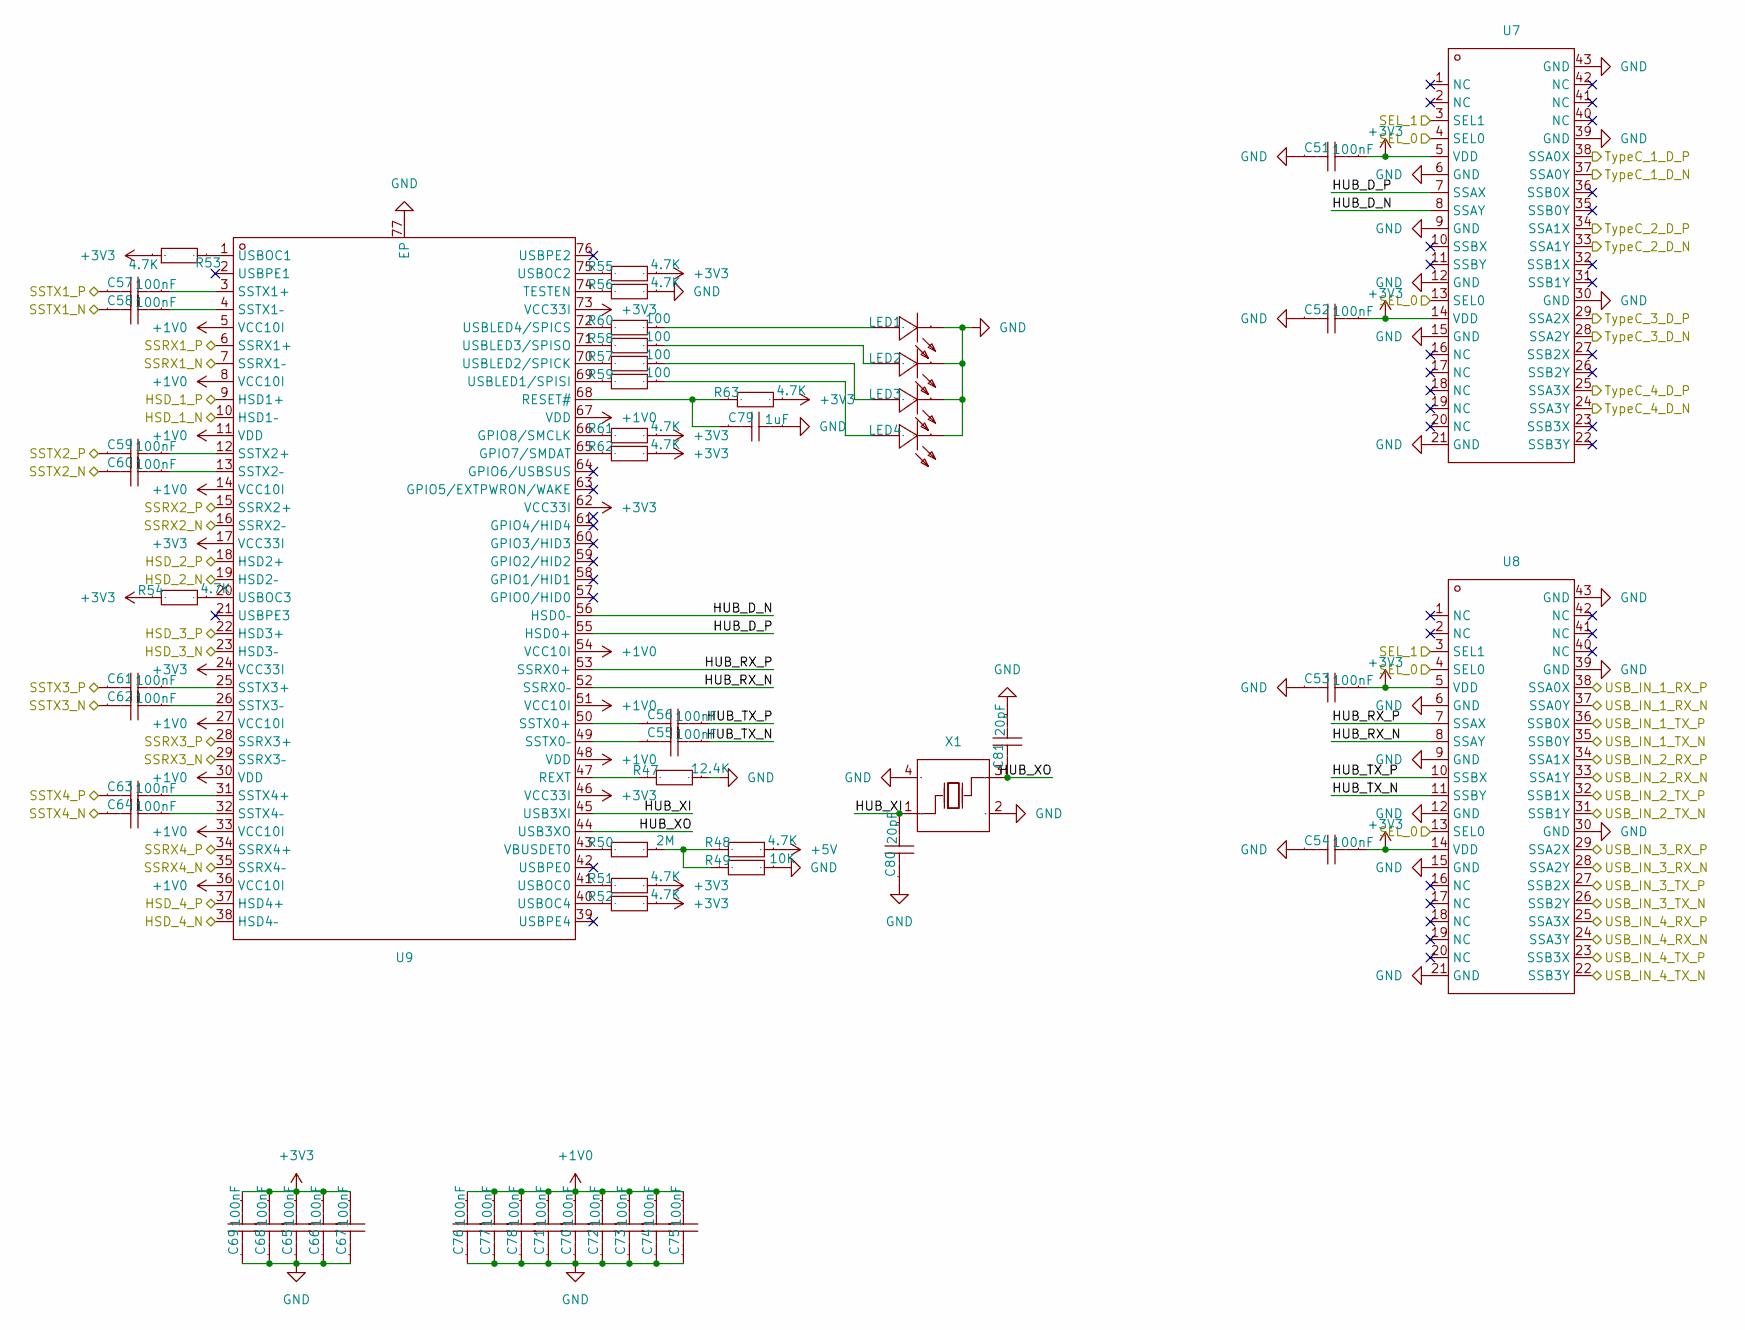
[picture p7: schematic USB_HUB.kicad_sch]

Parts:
C51, C52, C53, C54, C55, C56, C57, C58, C59, C60, C61, C62, C63, C64, C65, C66, C67, C68, C69, C70, C71, C72, C73, C74, C75, C76, C77, C78: 100nF; C0603; Manufacturer Part CL10A105KB8NNNC; LCSC Part Name 1uF ±10% 50V
C79: 1uF; C0603; Manufacturer Part CL10A105KB8NNNC; LCSC Part Name 1uF ±10% 50V
C80, C81: 20pF; C0603; Manufacturer Part CL10A105KB8NNNC; LCSC Part Name 1uF ±10% 50V
LED1, LED2, LED3, LED4: LED0603-RD; Manufacturer Part LTST-C190KSKT; LCSC Part Name 黄灯
R47: 12.4K; R0603; Manufacturer Part 0603WAF1002T5E; LCSC Part Name 厚膜电阻 10kΩ ±1% 100mW
R48, R51, R52, R53, R54, R55, R56, R61, R62, R63: 4.7K; R0603; Manufacturer Part 0603WAF1002T5E; LCSC Part Name 厚膜电阻 10kΩ ±1% 100mW
R49: 10K; R0603; Manufacturer Part 0603WAF1002T5E; LCSC Part Name 厚膜电阻 10kΩ ±1% 100mW
R50: 2M; R0603; Manufacturer Part 0603WAF1002T5E; LCSC Part Name 厚膜电阻 10kΩ ±1% 100mW
R57, R58, R59, R60: 100; R0603; Manufacturer Part 0603WAF1002T5E; LCSC Part Name 厚膜电阻 10kΩ ±1% 100mW
U7, U8: QFN-42_L9.0-W3.5-P0.50-EP7.6; Manufacturer Part CH484M; LCSC Part Name 差分通道四选一、四刀四掷超高速模拟开关芯片CH484M
U9: QFN-76_L9.0-W9.0-P0.40-EP6.3-TL; Manufacturer Part VL822-QFN76; LCSC Part Name VL822 USB 3.1 Gen2 Hub Controller
X1: 25MHz; CRYSTAL-SMD_4P-L3.2-W2.5-BL; Manufacturer Part TAXM11.0592M4RLBCCT2T; LCSC Part Name 11.0592MHz ±10ppm 20pF

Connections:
+1V0: C70.1, C71.1, C72.1, C73.1, C74.1, C75.1, C76.1, C77.1, C78.1, U9.5 (VCC10I), U9.8 (VCC10I), U9.11 (VDD), U9.14 (VCC10I), U9.27 (VCC10I), U9.30 (VDD), U9.33 (VCC10I), U9.36 (VCC10I), U9.48 (VDD), U9.51 (VCC10I), U9.54 (VCC10I), U9.67 (VDD); also elsewhere on the board
+3V3: C51.1, C52.1, C53.1, C54.1, C65.1, C66.1, C67.1, C68.1, C69.1, R51.1, R52.1, R53.1, R54.2, R55.1, R61.1, R62.1, R63.1, U7.5 (VDD), U7.14 (VDD), U8.5 (VDD), U8.14 (VDD), U9.17 (VCC33I), U9.24 (VCC33I), U9.46 (VCC33I), U9.62 (VCC33I), U9.73 (VCC33I); also elsewhere on the board
+5V: R48.1; also elsewhere on the board
/MCU/HUB_SEL0: U7.4 (SEL0), U7.13 (SEL0), U8.4 (SEL0), U8.13 (SEL0); also elsewhere on the board
/MCU/HUB_SEL1: U7.3 (SEL1), U8.3 (SEL1); also elsewhere on the board
/OUT_HUB/HSD_1_N: U9.10 (HSD1–); also elsewhere on the board
/OUT_HUB/HSD_1_P: U9.9 (HSD1+); also elsewhere on the board
/OUT_HUB/HSD_2_N: U9.19 (HSD2–); also elsewhere on the board
/OUT_HUB/HSD_2_P: U9.18 (HSD2+); also elsewhere on the board
/OUT_HUB/HSD_3_N: U9.23 (HSD3–); also elsewhere on the board
/OUT_HUB/HSD_3_P: U9.22 (HSD3+); also elsewhere on the board
/OUT_HUB/HSD_4_N: U9.38 (HSD4–); also elsewhere on the board
/OUT_HUB/HSD_4_P: U9.37 (HSD4+); also elsewhere on the board
/OUT_HUB/SSRX1_N: U9.7 (SSRX1–); also elsewhere on the board
/OUT_HUB/SSRX1_P: U9.6 (SSRX1+); also elsewhere on the board
/OUT_HUB/SSRX2_N: U9.16 (SSRX2–); also elsewhere on the board
/OUT_HUB/SSRX2_P: U9.15 (SSRX2+); also elsewhere on the board
/OUT_HUB/SSRX3_N: U9.29 (SSRX3–); also elsewhere on the board
/OUT_HUB/SSRX3_P: U9.28 (SSRX3+); also elsewhere on the board
/OUT_HUB/SSRX4_N: U9.35 (SSRX4–); also elsewhere on the board
/OUT_HUB/SSRX4_P: U9.34 (SSRX4+); also elsewhere on the board
/OUT_HUB/SSTX1_N: C58.2; also elsewhere on the board
/OUT_HUB/SSTX1_P: C57.2; also elsewhere on the board
/OUT_HUB/SSTX2_N: C60.2; also elsewhere on the board
/OUT_HUB/SSTX2_P: C59.2; also elsewhere on the board
/OUT_HUB/SSTX3_N: C62.2; also elsewhere on the board
/OUT_HUB/SSTX3_P: C61.2; also elsewhere on the board
/OUT_HUB/SSTX4_N: C64.2; also elsewhere on the board
/OUT_HUB/SSTX4_P: C63.2; also elsewhere on the board
/TypeC3.0Handle/TypeC_1_D_N: U7.37 (SSA0Y); also elsewhere on the board
/TypeC3.0Handle/TypeC_1_D_P: U7.38 (SSA0X); also elsewhere on the board
/TypeC3.0Handle/TypeC_2_D_N: U7.33 (SSA1Y); also elsewhere on the board
/TypeC3.0Handle/TypeC_2_D_P: U7.34 (SSA1X); also elsewhere on the board
/TypeC3.0Handle/TypeC_3_D_N: U7.28 (SSA2Y); also elsewhere on the board
/TypeC3.0Handle/TypeC_3_D_P: U7.29 (SSA2X); also elsewhere on the board
/TypeC3.0Handle/TypeC_4_D_N: U7.24 (SSA3Y); also elsewhere on the board
/TypeC3.0Handle/TypeC_4_D_P: U7.25 (SSA3X); also elsewhere on the board
/TypeC3.0Handle/USB_IN_1_RX_N: U8.37 (SSA0Y); also elsewhere on the board
/TypeC3.0Handle/USB_IN_1_RX_P: U8.38 (SSA0X); also elsewhere on the board
/TypeC3.0Handle/USB_IN_1_TX_N: U8.35 (SSB0Y); also elsewhere on the board
/TypeC3.0Handle/USB_IN_1_TX_P: U8.36 (SSB0X); also elsewhere on the board
/TypeC3.0Handle/USB_IN_2_RX_N: U8.33 (SSA1Y); also elsewhere on the board
/TypeC3.0Handle/USB_IN_2_RX_P: U8.34 (SSA1X); also elsewhere on the board
/TypeC3.0Handle/USB_IN_2_TX_N: U8.31 (SSB1Y); also elsewhere on the board
/TypeC3.0Handle/USB_IN_2_TX_P: U8.32 (SSB1X); also elsewhere on the board
/TypeC3.0Handle/USB_IN_3_RX_N: U8.28 (SSA2Y); also elsewhere on the board
/TypeC3.0Handle/USB_IN_3_RX_P: U8.29 (SSA2X); also elsewhere on the board
/TypeC3.0Handle/USB_IN_3_TX_N: U8.26 (SSB2Y); also elsewhere on the board
/TypeC3.0Handle/USB_IN_3_TX_P: U8.27 (SSB2X); also elsewhere on the board
/TypeC3.0Handle/USB_IN_4_RX_N: U8.24 (SSA3Y); also elsewhere on the board
/TypeC3.0Handle/USB_IN_4_RX_P: U8.25 (SSA3X); also elsewhere on the board
/TypeC3.0Handle/USB_IN_4_TX_N: U8.22 (SSB3Y); also elsewhere on the board
/TypeC3.0Handle/USB_IN_4_TX_P: U8.23 (SSB3X); also elsewhere on the board
/USB_HUB/HUB_D_N: U7.8 (SSAY), U9.56 (HSD0–)
/USB_HUB/HUB_D_P: U7.7 (SSAX), U9.55 (HSD0+)
/USB_HUB/HUB_RX_N: U8.8 (SSAY), U9.52 (SSRX0–)
/USB_HUB/HUB_RX_P: U8.7 (SSAX), U9.53 (SSRX0+)
/USB_HUB/HUB_TX_N: C55.1, U8.11 (SSBY)
/USB_HUB/HUB_TX_P: C56.1, U8.10 (SSBX)
/USB_HUB/HUB_XI: C80.1, U9.45 (USB3XI), X1.1 (OSC1)
/USB_HUB/HUB_XO: C81.2, U9.44 (USB3XO), X1.3 (OSC2)
GND: C51.2, C52.2, C53.2, C54.2, C65.2, C66.2, C67.2, C68.2, C69.2, C70.2, C71.2, C72.2, C73.2, C74.2, C75.2, C76.2, C77.2, C78.2, C79.1, C80.2, C81.1, LED1.1 (-), LED2.1 (-), LED3.1 (-), LED4.1 (-), R47.1, R49.1, R56.1, U7.6 (GND), U7.9 (GND), U7.12 (GND), U7.15 (GND), U7.21 (GND), U7.30 (GND), U7.39 (GND), U7.43 (GND), U8.6 (GND), U8.9 (GND), U8.12 (GND), U8.15 (GND), U8.21 (GND), U8.30 (GND), U8.39 (GND), U8.43 (GND), U9.77 (EP), X1.2 (GND), X1.4 (GND); also elsewhere on the board
unnamed: LED1.2 (+), R60.1
unnamed: LED2.2 (+), R58.1
unnamed: LED3.2 (+), R57.1
unnamed: LED4.2 (+), R59.1
unnamed: R48.2, R49.2, R50.1
unnamed: R62.2, U9.65 (GPIO7/SMDAT)
unnamed: R61.2, U9.66 (GPIO8/SMCLK)
unnamed: C79.2, R63.2, U9.68 (RESET#)
unnamed: R47.2, U9.47 (REXT)
unnamed: C56.2, U9.50 (SSTX0+)
unnamed: C55.2, U9.49 (SSTX0–)
unnamed: C57.1, U9.3 (SSTX1+)
unnamed: C58.1, U9.4 (SSTX1–)
unnamed: C59.1, U9.12 (SSTX2+)
unnamed: C60.1, U9.13 (SSTX2–)
unnamed: C61.1, U9.25 (SSTX3+)
unnamed: C62.1, U9.26 (SSTX3–)
unnamed: C63.1, U9.31 (SSTX4+)
unnamed: C64.1, U9.32 (SSTX4–)
unnamed: R56.2, U9.74 (TESTEN)
unnamed: R59.2, U9.69 (USBLED1/SPISI)
unnamed: R57.2, U9.70 (USBLED2/SPICK)
unnamed: R58.2, U9.71 (USBLED3/SPISO)
unnamed: R60.2, U9.72 (USBLED4/SPICS)
unnamed: R51.2, U9.41 (USBOC0)
unnamed: R53.2, U9.1 (USBOC1)
unnamed: R55.2, U9.75 (USBOC2)
unnamed: R54.1, U9.20 (USBOC3)
unnamed: R52.2, U9.40 (USBOC4)
unnamed: R50.2, U9.43 (VBUSDET0)

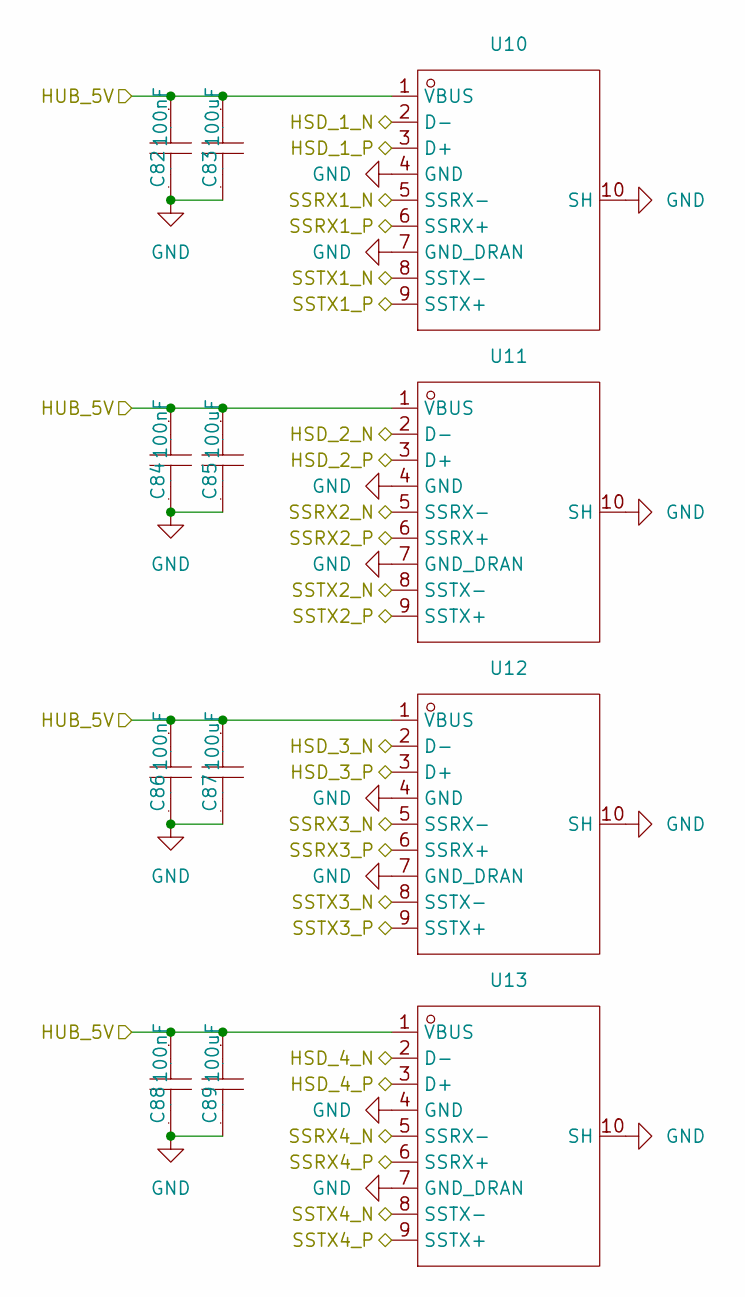
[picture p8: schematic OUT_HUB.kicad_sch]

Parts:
C82, C84, C86, C88: 100nF; C0603; Manufacturer Part CL10A105KB8NNNC; LCSC Part Name 1uF ±10% 50V
C83, C85, C87, C89: 100uF; C0603; Manufacturer Part CL10A105KB8NNNC; LCSC Part Name 1uF ±10% 50V
U10, U11, U12, U13: USB-TH_USB3.0-A; Manufacturer Part HC-USB3.0-L168-WP; LCSC Part Name Type-A 母 弯插 USB3.0 A母90度 弯脚蓝色平口 吸塑盒

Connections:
+5V: C82.1, C83.1, C84.1, C85.1, C86.1, C87.1, C88.1, C89.1, U10.1 (VBUS), U11.1 (VBUS), U12.1 (VBUS), U13.1 (VBUS); also elsewhere on the board
/OUT_HUB/HSD_1_N: U10.2 (D-); also elsewhere on the board
/OUT_HUB/HSD_1_P: U10.3 (D+); also elsewhere on the board
/OUT_HUB/HSD_2_N: U11.2 (D-); also elsewhere on the board
/OUT_HUB/HSD_2_P: U11.3 (D+); also elsewhere on the board
/OUT_HUB/HSD_3_N: U12.2 (D-); also elsewhere on the board
/OUT_HUB/HSD_3_P: U12.3 (D+); also elsewhere on the board
/OUT_HUB/HSD_4_N: U13.2 (D-); also elsewhere on the board
/OUT_HUB/HSD_4_P: U13.3 (D+); also elsewhere on the board
/OUT_HUB/SSRX1_N: U10.5 (SSRX-); also elsewhere on the board
/OUT_HUB/SSRX1_P: U10.6 (SSRX+); also elsewhere on the board
/OUT_HUB/SSRX2_N: U11.5 (SSRX-); also elsewhere on the board
/OUT_HUB/SSRX2_P: U11.6 (SSRX+); also elsewhere on the board
/OUT_HUB/SSRX3_N: U12.5 (SSRX-); also elsewhere on the board
/OUT_HUB/SSRX3_P: U12.6 (SSRX+); also elsewhere on the board
/OUT_HUB/SSRX4_N: U13.5 (SSRX-); also elsewhere on the board
/OUT_HUB/SSRX4_P: U13.6 (SSRX+); also elsewhere on the board
/OUT_HUB/SSTX1_N: U10.8 (SSTX-); also elsewhere on the board
/OUT_HUB/SSTX1_P: U10.9 (SSTX+); also elsewhere on the board
/OUT_HUB/SSTX2_N: U11.8 (SSTX-); also elsewhere on the board
/OUT_HUB/SSTX2_P: U11.9 (SSTX+); also elsewhere on the board
/OUT_HUB/SSTX3_N: U12.8 (SSTX-); also elsewhere on the board
/OUT_HUB/SSTX3_P: U12.9 (SSTX+); also elsewhere on the board
/OUT_HUB/SSTX4_N: U13.8 (SSTX-); also elsewhere on the board
/OUT_HUB/SSTX4_P: U13.9 (SSTX+); also elsewhere on the board
GND: C82.2, C83.2, C84.2, C85.2, C86.2, C87.2, C88.2, C89.2, U10.4 (GND), U10.7 (GND_DRAN), U10.10 (SH), U11.4 (GND), U11.7 (GND_DRAN), U11.10 (SH), U12.4 (GND), U12.7 (GND_DRAN), U12.10 (SH), U13.4 (GND), U13.7 (GND_DRAN), U13.10 (SH); also elsewhere on the board

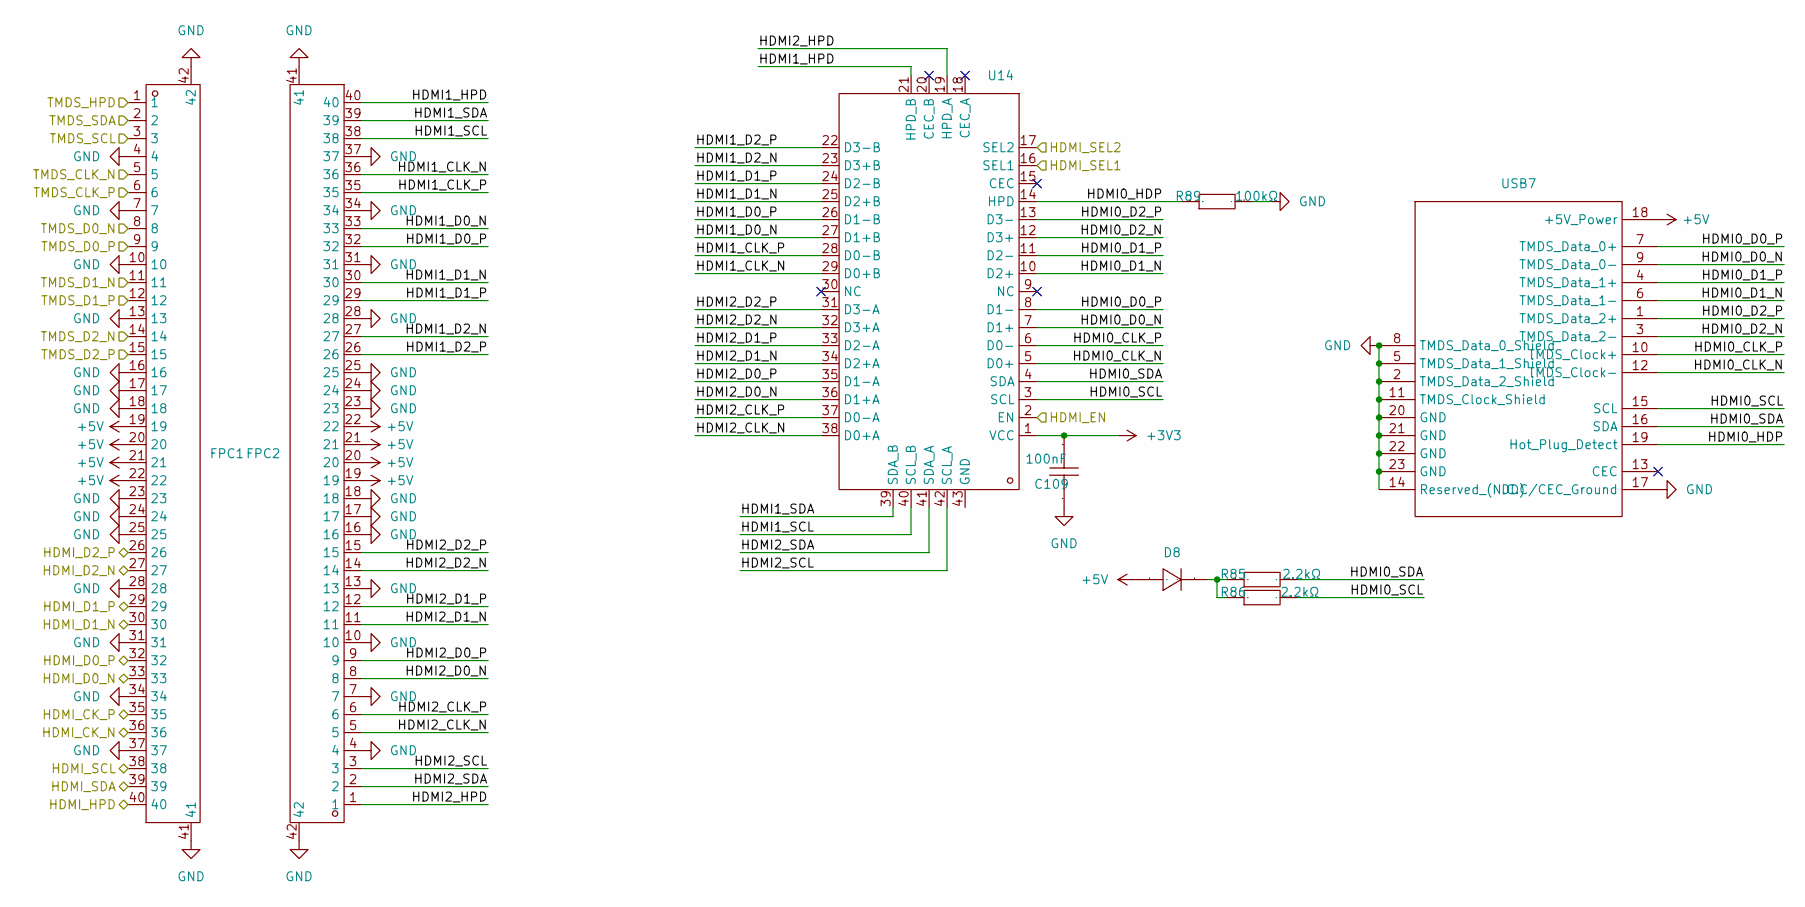
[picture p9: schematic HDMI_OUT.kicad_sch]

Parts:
C109: 100nF; C0603; Manufacturer Part CL10A105KB8NNNC; LCSC Part Name 1uF ±10% 50V
D8: SOD-323F_L1.7-W1.3-LS2.5-R-RD; Manufacturer Part 1N4148WSL; LCSC Part Name 1N4148WSL
FPC1, FPC2: FPC-SMD_40P-P0.50_XUNPU_FPC-05FB-40PH20; Manufacturer Part FPC-05FB-40PH20; LCSC Part Name 翻盖式 卧贴 P数:40P 间距:0.5mm
R85, R86: 2.2kΩ; R0603; Manufacturer Part 0603WAF1002T5E; LCSC Part Name 厚膜电阻 10kΩ ±1% 100mW
R89: 100kΩ; R0603; Manufacturer Part 0603WAF1002T5E; LCSC Part Name 厚膜电阻 10kΩ ±1% 100mW
U14: WFQFN-42_L9.0-W3.5-P0.50-BL-EP; Manufacturer Part TS3DV642A0RUAR; LCSC Part Name 具有1.8V兼容控制和断电模式的12通道1:2多路复用器/多路解复用器
USB7: HDMI-SMD_HDMI-001S; Manufacturer Part HDMI-001S; LCSC Part Name HDMI-001S

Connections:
+3V3: C109.1, U14.1 (VCC); also elsewhere on the board
+5V: D8.2, FPC1.19, FPC1.20, FPC1.21, FPC1.22, FPC2.19, FPC2.20, FPC2.21, FPC2.22, USB7.18 (+5V_Power); also elsewhere on the board
/HDMI_OUT/HDMI0_CLK_N: U14.5 (D0+), USB7.12 (TMDS_Clock-)
/HDMI_OUT/HDMI0_CLK_P: U14.6 (D0-), USB7.10 (TMDS_Clock+)
/HDMI_OUT/HDMI0_D0_N: U14.7 (D1+), USB7.9 (TMDS_Data_0-)
/HDMI_OUT/HDMI0_D0_P: U14.8 (D1-), USB7.7 (TMDS_Data_0+)
/HDMI_OUT/HDMI0_D1_N: U14.10 (D2+), USB7.6 (TMDS_Data_1-)
/HDMI_OUT/HDMI0_D1_P: U14.11 (D2-), USB7.4 (TMDS_Data_1+)
/HDMI_OUT/HDMI0_D2_N: U14.12 (D3+), USB7.3 (TMDS_Data_2-)
/HDMI_OUT/HDMI0_D2_P: U14.13 (D3-), USB7.1 (TMDS_Data_2+)
/HDMI_OUT/HDMI0_HDP: R89.1, U14.14 (HPD), USB7.19 (Hot_Plug_Detect)
/HDMI_OUT/HDMI0_SCL: R86.2, U14.3 (SCL), USB7.15 (SCL)
/HDMI_OUT/HDMI0_SDA: R85.2, U14.4 (SDA), USB7.16 (SDA)
/HDMI_OUT/HDMI1_CLK_N: FPC2.36, U14.29 (D0+B)
/HDMI_OUT/HDMI1_CLK_P: FPC2.35, U14.28 (D0-B)
/HDMI_OUT/HDMI1_D0_N: FPC2.33, U14.27 (D1+B)
/HDMI_OUT/HDMI1_D0_P: FPC2.32, U14.26 (D1-B)
/HDMI_OUT/HDMI1_D1_N: FPC2.30, U14.25 (D2+B)
/HDMI_OUT/HDMI1_D1_P: FPC2.29, U14.24 (D2-B)
/HDMI_OUT/HDMI1_D2_N: FPC2.27, U14.23 (D3+B)
/HDMI_OUT/HDMI1_D2_P: FPC2.26, U14.22 (D3-B)
/HDMI_OUT/HDMI1_HPD: FPC2.40, U14.21 (HPD_B)
/HDMI_OUT/HDMI1_SCL: FPC2.38, U14.40 (SCL_B)
/HDMI_OUT/HDMI1_SDA: FPC2.39, U14.39 (SDA_B)
/HDMI_OUT/HDMI2_CLK_N: FPC2.5, U14.38 (D0+A)
/HDMI_OUT/HDMI2_CLK_P: FPC2.6, U14.37 (D0-A)
/HDMI_OUT/HDMI2_D0_N: FPC2.8, U14.36 (D1+A)
/HDMI_OUT/HDMI2_D0_P: FPC2.9, U14.35 (D1-A)
/HDMI_OUT/HDMI2_D1_N: FPC2.11, U14.34 (D2+A)
/HDMI_OUT/HDMI2_D1_P: FPC2.12, U14.33 (D2-A)
/HDMI_OUT/HDMI2_D2_N: FPC2.14, U14.32 (D3+A)
/HDMI_OUT/HDMI2_D2_P: FPC2.15, U14.31 (D3-A)
/HDMI_OUT/HDMI2_HPD: FPC2.1, U14.19 (HPD_A)
/HDMI_OUT/HDMI2_SCL: FPC2.3, U14.42 (SCL_A)
/HDMI_OUT/HDMI2_SDA: FPC2.2, U14.41 (SDA_A)
/HDMI_OUT/HDMI_CK_N: FPC1.36; also elsewhere on the board
/HDMI_OUT/HDMI_CK_P: FPC1.35; also elsewhere on the board
/HDMI_OUT/HDMI_D0_N: FPC1.33; also elsewhere on the board
/HDMI_OUT/HDMI_D0_P: FPC1.32; also elsewhere on the board
/HDMI_OUT/HDMI_D1_N: FPC1.30; also elsewhere on the board
/HDMI_OUT/HDMI_D1_P: FPC1.29; also elsewhere on the board
/HDMI_OUT/HDMI_D2_N: FPC1.27; also elsewhere on the board
/HDMI_OUT/HDMI_D2_P: FPC1.26; also elsewhere on the board
/HDMI_OUT/HDMI_HPD: FPC1.40; also elsewhere on the board
/HDMI_OUT/HDMI_SCL: FPC1.38; also elsewhere on the board
/HDMI_OUT/HDMI_SDA: FPC1.39; also elsewhere on the board
/HDMI_OUT/TMDS_CLK_N: FPC1.5; also elsewhere on the board
/HDMI_OUT/TMDS_CLK_P: FPC1.6; also elsewhere on the board
/HDMI_OUT/TMDS_D0_N: FPC1.8; also elsewhere on the board
/HDMI_OUT/TMDS_D0_P: FPC1.9; also elsewhere on the board
/HDMI_OUT/TMDS_D1_N: FPC1.11; also elsewhere on the board
/HDMI_OUT/TMDS_D1_P: FPC1.12; also elsewhere on the board
/HDMI_OUT/TMDS_D2_N: FPC1.14; also elsewhere on the board
/HDMI_OUT/TMDS_D2_P: FPC1.15; also elsewhere on the board
/HDMI_OUT/TMDS_HPD: FPC1.1; also elsewhere on the board
/HDMI_OUT/TMDS_SCL: FPC1.3; also elsewhere on the board
/HDMI_OUT/TMDS_SDA: FPC1.2; also elsewhere on the board
/MCU/HDMI_EN: U14.2 (EN); also elsewhere on the board
/MCU/HDMI_SEL1: U14.16 (SEL1); also elsewhere on the board
/MCU/HDMI_SEL2: U14.17 (SEL2); also elsewhere on the board
GND: C109.2, FPC1.4, FPC1.7, FPC1.10, FPC1.13, FPC1.16, FPC1.17, FPC1.18, FPC1.23, FPC1.24, FPC1.25, FPC1.28, FPC1.31, FPC1.34, FPC1.37, FPC1.41, FPC1.42, FPC2.4, FPC2.7, FPC2.10, FPC2.13, FPC2.16, FPC2.17, FPC2.18, FPC2.23, FPC2.24, FPC2.25, FPC2.28, FPC2.31, FPC2.34, FPC2.37, FPC2.41, FPC2.42, R89.2, USB7.2 (TMDS_Data_2_Shield), USB7.5 (TMDS_Data_1_Shield), USB7.8 (TMDS_Data_0_Shield), USB7.11 (TMDS_Clock_Shield), USB7.14 (Reserved_(N.C.)), USB7.17 (DDC/CEC_Ground), USB7.20 (GND), USB7.21 (GND), USB7.22 (GND), USB7.23 (GND); also elsewhere on the board
unnamed: D8.1, R85.1, R86.1

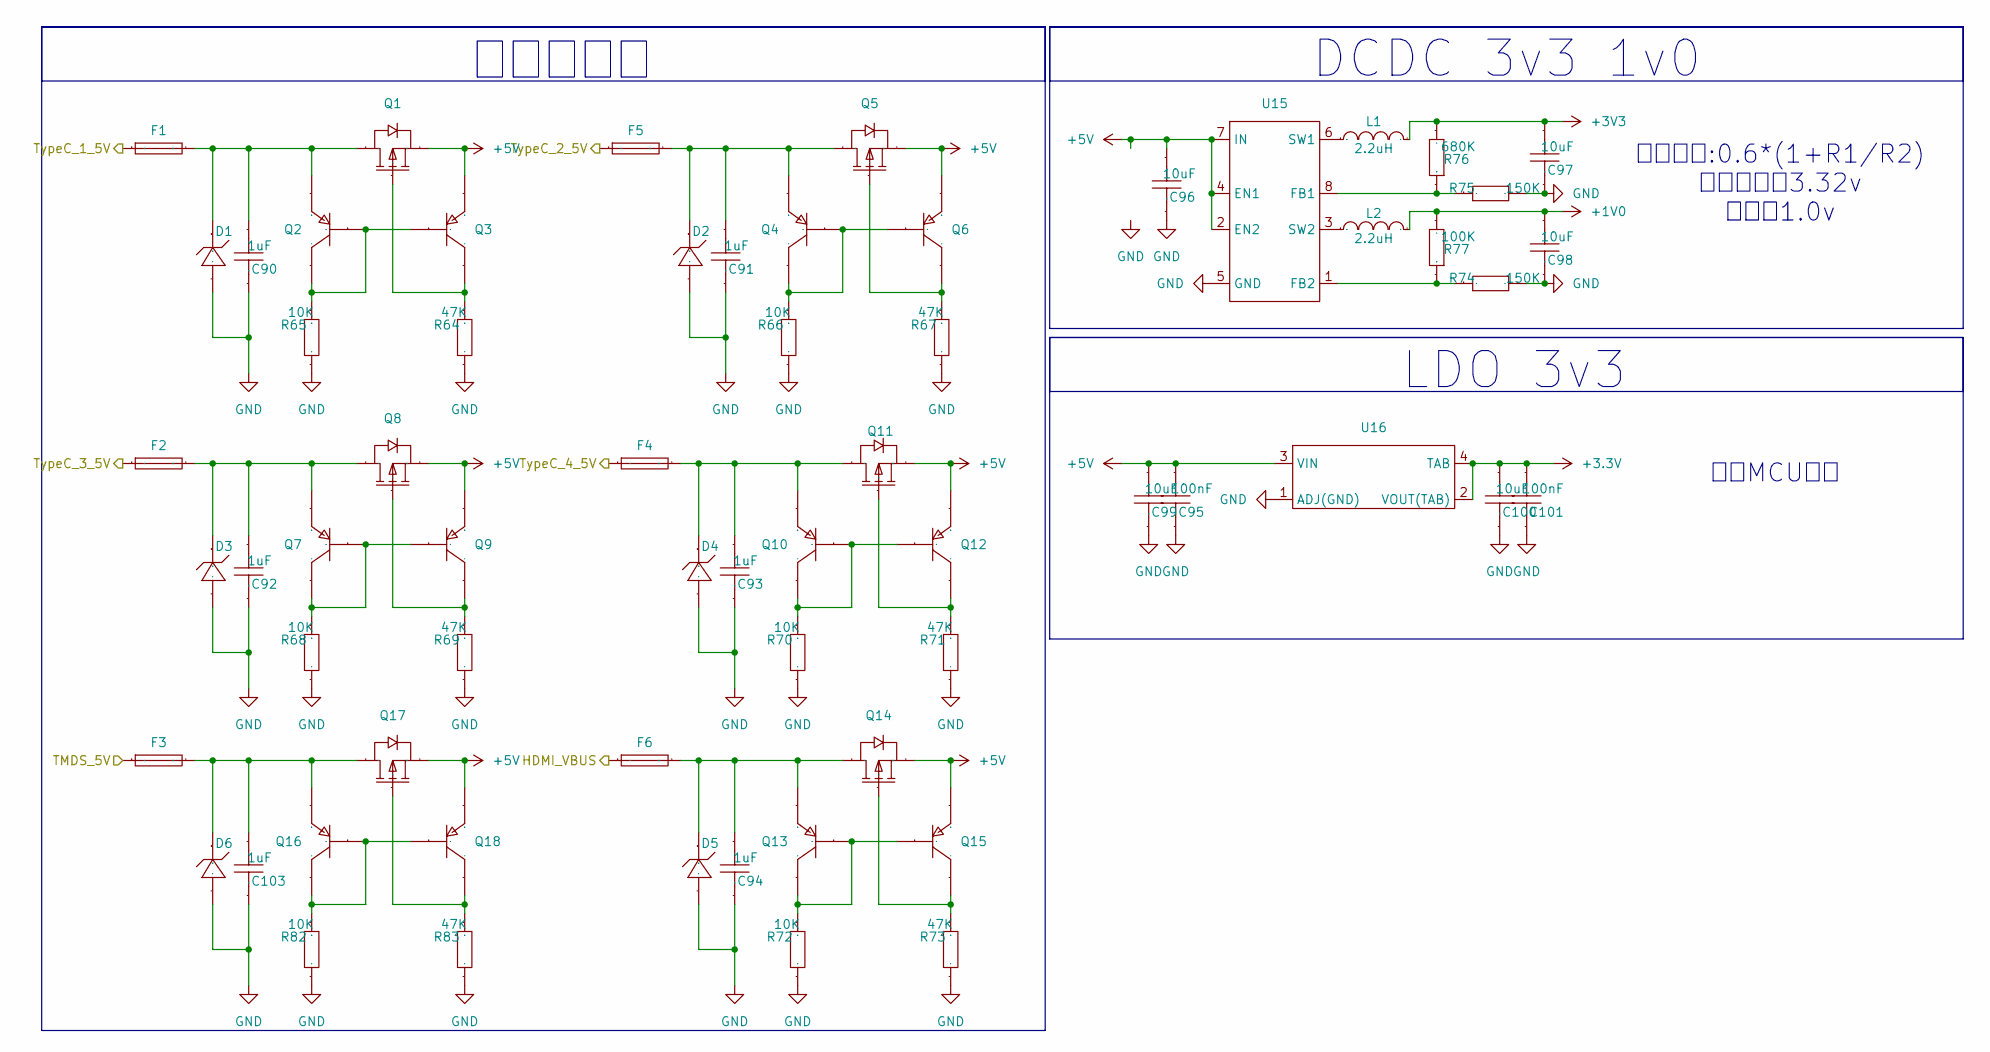
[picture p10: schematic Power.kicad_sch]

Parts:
C90, C91, C92, C93, C94, C103: 1uF; C0603; Manufacturer Part CL10A105KB8NNNC; LCSC Part Name 1uF ±10% 50V
C95, C101: 100nF; C0603; Manufacturer Part CL10A105KB8NNNC; LCSC Part Name 1uF ±10% 50V
C96, C97, C98, C99, C100: 10uF; C0603; Manufacturer Part CL10A105KB8NNNC; LCSC Part Name 1uF ±10% 50V
D1, D2, D3, D4, D5, D6: SMB_L4.6-W3.6-LS5.3-RD; Manufacturer Part SMBJ5.0A; LCSC Part Name 单向TVS 5V截止 峰值浪涌电流：65.3A@10/1000us
F1, F2, F3, F4, F5, F6: F1206; Manufacturer Part SMD1206-050-33; LCSC Part Name SMD1206-050-33
L1, L2: 2.2uH; IND-SMD_L7.0-W6.6; Manufacturer Part FXL0630-2R2-M; LCSC Part Name 2.2uH ±20% 10A
Q1, Q5, Q8, Q11, Q14, Q17: SOT-23-3_L2.9-W1.3-P0.95-LS2.4-BR-1; Manufacturer Part DMG2305UX; LCSC Part Name 耐压:20V 电流:4.1A
Q2, Q3, Q4, Q6, Q7, Q9, Q10, Q12, Q13, Q15, Q16, Q18: SOT-23-3_L2.9-W1.3-P1.90-LS2.4-BR; Manufacturer Part MMBT4403LT1G; LCSC Part Name PNP 电流:600mA 电压:40V
R64, R67, R69, R71, R73, R83: 47K; R0603; Manufacturer Part 0603WAF1002T5E; LCSC Part Name 厚膜电阻 10kΩ ±1% 100mW
R65, R66, R68, R70, R72, R82: 10K; R0603; Manufacturer Part 0603WAF1002T5E; LCSC Part Name 厚膜电阻 10kΩ ±1% 100mW
R74, R75: 150K; R0603; Manufacturer Part 0603WAF1002T5E; LCSC Part Name 厚膜电阻 10kΩ ±1% 100mW
R76: 680K; R0603; Manufacturer Part 0603WAF1002T5E; LCSC Part Name 厚膜电阻 10kΩ ±1% 100mW
R77: 100K; R0603; Manufacturer Part 0603WAF1002T5E; LCSC Part Name 厚膜电阻 10kΩ ±1% 100mW
U15: TSOT-23-8_L2.9-W1.6-P0.65-LS2.8-BL; Manufacturer Part MP2122AGJ-Z; LCSC Part Name 6V, 2A, 低静态电流, 双路同步降压稳压器
U16: SOT-223-4_L6.5-W3.5-P2.30-LS7.0-BR; Manufacturer Part AMS1117-3.3; LCSC Part Name 输出:3.3V 电流:1A 耐压:12V

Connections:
+1V0: C98.2, L2.2, R77.2; also elsewhere on the board
+3.3V: C100.2, C101.2, U16.2 (VOUT(TAB)), U16.4 (TAB); also elsewhere on the board
+3V3: C97.2, L1.2, R76.2; also elsewhere on the board
+5V: C95.2, C96.2, C99.2, Q1.2 (S), Q3.2 (E), Q5.2 (S), Q6.2 (E), Q8.2 (S), Q9.2 (E), Q11.2 (S), Q12.2 (E), Q14.2 (S), Q15.2 (E), Q17.2 (S), Q18.2 (E), U15.2 (EN2), U15.4 (EN1), U15.7 (IN), U16.3 (VIN); also elsewhere on the board
/Power/HDMI_VBUS: F6.1; also elsewhere on the board
/Power/TMDS_5V: F3.1; also elsewhere on the board
/Power/TypeC_1_5V: F1.1; also elsewhere on the board
/Power/TypeC_2_5V: F5.1; also elsewhere on the board
/Power/TypeC_3_5V: F2.1; also elsewhere on the board
/Power/TypeC_4_5V: F4.1; also elsewhere on the board
GND: C90.1, C91.1, C92.1, C93.1, C94.1, C95.1, C96.1, C97.1, C98.1, C99.1, C100.1, C101.1, C103.1, D1.2, D2.2, D3.2, D4.2, D5.2, D6.2, R64.2, R65.2, R66.2, R67.2, R68.2, R69.2, R70.2, R71.2, R72.2, R73.2, R74.2, R75.2, R82.2, R83.2, U15.5 (GND), U16.1 (ADJ(GND)); also elsewhere on the board
unnamed: C90.2, D1.1, F1.2, Q1.3 (D), Q2.2 (E)
unnamed: Q1.1 (G), Q3.3 (C), R64.1
unnamed: Q2.1 (B), Q2.3 (C), Q3.1 (B), R65.1
unnamed: Q4.1 (B), Q4.3 (C), Q6.1 (B), R66.1
unnamed: C91.2, D2.1, F5.2, Q4.2 (E), Q5.3 (D)
unnamed: Q5.1 (G), Q6.3 (C), R67.1
unnamed: Q7.1 (B), Q7.3 (C), Q9.1 (B), R68.1
unnamed: C92.2, D3.1, F2.2, Q7.2 (E), Q8.3 (D)
unnamed: Q8.1 (G), Q9.3 (C), R69.1
unnamed: Q10.1 (B), Q10.3 (C), Q12.1 (B), R70.1
unnamed: C93.2, D4.1, F4.2, Q10.2 (E), Q11.3 (D)
unnamed: Q11.1 (G), Q12.3 (C), R71.1
unnamed: Q13.1 (B), Q13.3 (C), Q15.1 (B), R72.1
unnamed: C94.2, D5.1, F6.2, Q13.2 (E), Q14.3 (D)
unnamed: Q14.1 (G), Q15.3 (C), R73.1
unnamed: Q16.1 (B), Q16.3 (C), Q18.1 (B), R82.1
unnamed: C103.2, D6.1, F3.2, Q16.2 (E), Q17.3 (D)
unnamed: Q17.1 (G), Q18.3 (C), R83.1
unnamed: R75.1, R76.1, U15.8 (FB1)
unnamed: R74.1, R77.1, U15.1 (FB2)
unnamed: L1.1, U15.6 (SW1)
unnamed: L2.1, U15.3 (SW2)

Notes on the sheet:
防浪涌电路
计算公式:0.6*(1+R1/R2) 上路输出为3.32v 下路为1.0v
LDO 3v3
负责MCU供电
DCDC 3v3 1v0

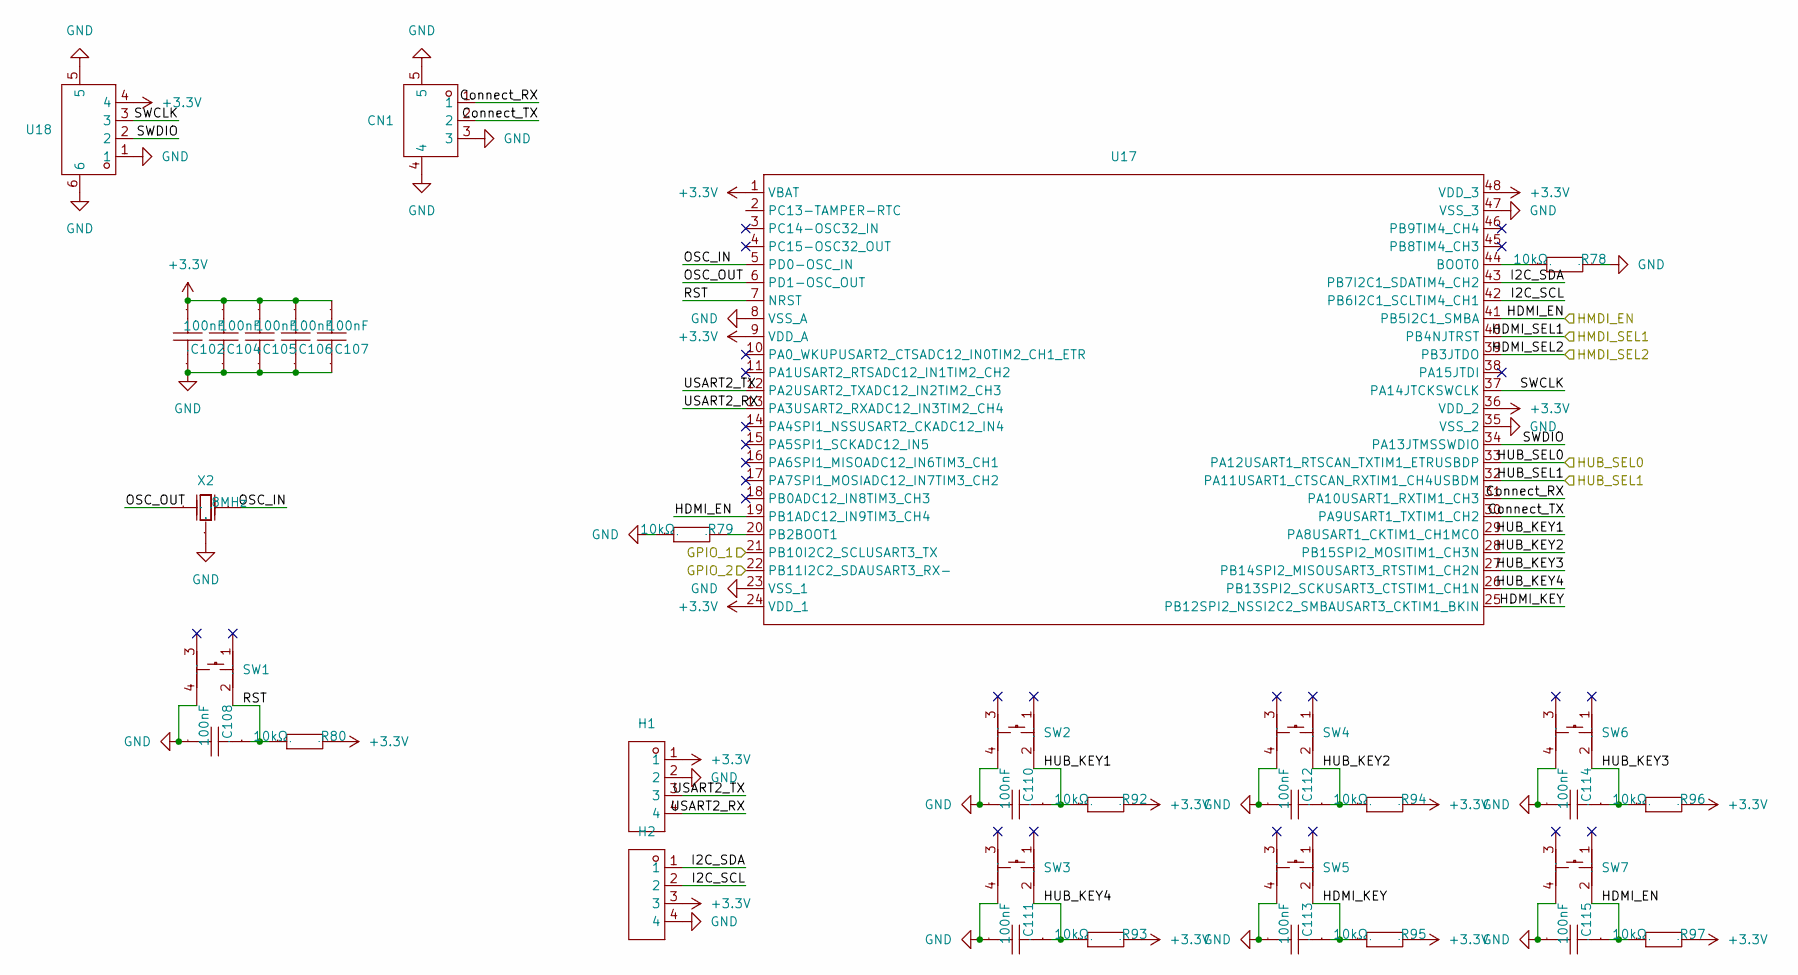
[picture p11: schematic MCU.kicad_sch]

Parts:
C102, C104, C105, C106, C107, C108, C110, C111, C112, C113, C114, C115: 100nF; C0603; Manufacturer Part CL10A105KB8NNNC; LCSC Part Name 1uF ±10% 50V
CN1: CONN-TH_3P-P1.25_GH1.25; Manufacturer Part WAFER-GH1.25-3PWB; LCSC Part Name 1x3P 间距:1.25mm 卧贴 系列:GH
H1, H2: HDR-TH_4P-P2.54-V-M; Manufacturer Part PZ254V-11-04P; LCSC Part Name 1x4P 间距:2.54mm 方针 直插
R78, R79, R80, R92, R93, R94, R95, R96, R97: 10kΩ; R0603; Manufacturer Part 0603WAF1002T5E; LCSC Part Name 厚膜电阻 10kΩ ±1% 100mW
SW1, SW2, SW3, SW4, SW5, SW6, SW7: SW-SMD_4P-L4.2-W3.2-P2.15-LS4.6-1; Manufacturer Part TS3425BA; LCSC Part Name 4.2*3.2*2.5mm 立贴 轻触开关
U17: LQFP-48_L7.0-W7.0-P0.50-LS9.0-BL; Manufacturer Part STM32F103CBT6; LCSC Part Name 主流增强型ARM Cortex-M3 MCU，具有128 KB Flash、7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
U18: CONN-SMD_4P-P1.25_XUNPU_WAFER-GH1.25-4PWB; Manufacturer Part WAFER-GH1.25-4PWB; LCSC Part Name 1x4P 间距:1.25mm 卧贴 系列:GH
X2: 8MHz; OSC-SMD_3P-L3.2-W1.3-P1.20-L; Manufacturer Part CSTNE8M00G550000R0; LCSC Part Name 8MHz ±0.5% 内置负载电容:33pF

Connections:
+3.3V: C102.2, C104.2, C105.2, C106.2, C107.2, H1.1, H2.3, R80.2, R92.2, R93.2, R94.2, R95.2, R96.2, R97.2, U17.1 (VBAT), U17.9 (VDD_A), U17.24 (VDD_1), U17.36 (VDD_2), U17.48 (VDD_3), U18.4; also elsewhere on the board
/MCU/Connect_RX: CN1.1, U17.31 (PA10USART1_RXTIM1_CH3)
/MCU/Connect_TX: CN1.2, U17.30 (PA9USART1_TXTIM1_CH2)
/MCU/GPIO_1: U17.21 (PB10I2C2_SCLUSART3_TX); also elsewhere on the board
/MCU/GPIO_2: U17.22 (PB11I2C2_SDAUSART3_RX-); also elsewhere on the board
/MCU/HDMI_EN: C115.1, R97.1, SW7.2, U17.19 (PB1ADC12_IN9TIM3_CH4), U17.41 (PB5I2C1_SMBA); also elsewhere on the board
/MCU/HDMI_KEY: C113.1, R95.1, SW5.2, U17.25 (PB12SPI2_NSSI2C2_SMBAUSART3_CKTIM1_BKIN)
/MCU/HDMI_SEL1: U17.40 (PB4NJTRST); also elsewhere on the board
/MCU/HDMI_SEL2: U17.39 (PB3JTDO); also elsewhere on the board
/MCU/HUB_KEY1: C110.1, R92.1, SW2.2, U17.29 (PA8USART1_CKTIM1_CH1MCO)
/MCU/HUB_KEY2: C112.1, R94.1, SW4.2, U17.28 (PB15SPI2_MOSITIM1_CH3N)
/MCU/HUB_KEY3: C114.1, R96.1, SW6.2, U17.27 (PB14SPI2_MISOUSART3_RTSTIM1_CH2N)
/MCU/HUB_KEY4: C111.1, R93.1, SW3.2, U17.26 (PB13SPI2_SCKUSART3_CTSTIM1_CH1N)
/MCU/HUB_SEL0: U17.33 (PA12USART1_RTSCAN_TXTIM1_ETRUSBDP); also elsewhere on the board
/MCU/HUB_SEL1: U17.32 (PA11USART1_CTSCAN_RXTIM1_CH4USBDM); also elsewhere on the board
/MCU/I2C_SCL: H2.2, U17.42 (PB6I2C1_SCLTIM4_CH1)
/MCU/I2C_SDA: H2.1, U17.43 (PB7I2C1_SDATIM4_CH2)
/MCU/OSC_IN: U17.5 (PD0-OSC_IN), X2.1 (OSC1)
/MCU/OSC_OUT: U17.6 (PD1-OSC_OUT), X2.3 (OSC2)
/MCU/RST: C108.1, R80.1, SW1.2, U17.7 (NRST)
/MCU/SWCLK: U17.37 (PA14JTCKSWCLK), U18.3
/MCU/SWDIO: U17.34 (PA13JTMSSWDIO), U18.2
/MCU/USART2_RX: H1.4, U17.13 (PA3USART2_RXADC12_IN3TIM2_CH4)
/MCU/USART2_TX: H1.3, U17.12 (PA2USART2_TXADC12_IN2TIM2_CH3)
GND: C102.1, C104.1, C105.1, C106.1, C107.1, C108.2, C110.2, C111.2, C112.2, C113.2, C114.2, C115.2, CN1.3, CN1.4, CN1.5, H1.2, H2.4, R78.2, R79.1, SW1.4, SW2.4, SW3.4, SW4.4, SW5.4, SW6.4, SW7.4, U17.8 (VSS_A), U17.23 (VSS_1), U17.35 (VSS_2), U17.47 (VSS_3), U18.1, U18.5, U18.6, X2.2 (GND); also elsewhere on the board
unnamed: R78.1, U17.44 (BOOT0)
unnamed: R79.2, U17.20 (PB2BOOT1)

Board: 2 copper layers, 291 parts (5 on the bottom side), 330 nets, no tracks yet.

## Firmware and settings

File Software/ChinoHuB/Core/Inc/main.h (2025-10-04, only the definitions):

#define HDMI_EN_Pin GPIO_PIN_1
#define HDMI_EN_GPIO_Port GPIOB
#define GPIO1_Pin GPIO_PIN_10
#define GPIO1_GPIO_Port GPIOB
#define GPIO2_Pin GPIO_PIN_11
#define GPIO2_GPIO_Port GPIOB
#define HDMI_KEY_Pin GPIO_PIN_12
#define HDMI_KEY_GPIO_Port GPIOB
#define HUB_KEY4_Pin GPIO_PIN_13
#define HUB_KEY4_GPIO_Port GPIOB
#define HUB_KEY3_Pin GPIO_PIN_14
#define HUB_KEY3_GPIO_Port GPIOB
#define HUB_KEY2_Pin GPIO_PIN_15
#define HUB_KEY2_GPIO_Port GPIOB
#define HUB_KEY1_Pin GPIO_PIN_8
#define HUB_KEY1_GPIO_Port GPIOA
#define Connect_TX_Pin GPIO_PIN_9
#define Connect_TX_GPIO_Port GPIOA
#define Connect_RX_Pin GPIO_PIN_10
#define Connect_RX_GPIO_Port GPIOA
#define HUB_SEL1_Pin GPIO_PIN_11
#define HUB_SEL1_GPIO_Port GPIOA
#define HUB_SEL0_Pin GPIO_PIN_12
#define HUB_SEL0_GPIO_Port GPIOA
#define HDMI_SEL2_Pin GPIO_PIN_3
#define HDMI_SEL2_GPIO_Port GPIOB
#define HDMI_SEL1_Pin GPIO_PIN_4
#define HDMI_SEL1_GPIO_Port GPIOB
#define HDMI_ENB5_Pin GPIO_PIN_5
#define HDMI_ENB5_GPIO_Port GPIOB

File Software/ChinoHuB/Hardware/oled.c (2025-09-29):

#include "oled.h"

// SSD1306指令宏定义
#define OLED_CMD_DISPLAY_OFF          	0xAE // 关闭显示
#define OLED_CMD_SET_CLOCK_DIV        	0xD5 // 设置时钟分频因子
#define OLED_CMD_SET_MULTIPLEX        	0xA8 // 设置复用率
#define OLED_CMD_SET_DISP_OFFSET      	0xD3 // 设置显示偏移
#define OLED_CMD_SET_START_LINE       	0x40 // 设置起始行
#define OLED_CMD_SET_SEGMENT_REMAP    	0xA1 // 设置段重映射
#define OLED_CMD_SET_COMSCAN_DEC      	0xC8 // 设置COM扫描方向为递减
#define OLED_CMD_SET_COM_PINS         	0xDA // 设置COM引脚配置
#define OLED_CMD_SET_CONTRAST         	0x81 // 设置对比度
#define OLED_CMD_SET_PRECHARGE        	0xD9 // 设置预充电周期
#define OLED_CMD_SET_VCOMH            	0xDB // 设置VCOMH电平
#define OLED_CMD_DISPLAY_ALL_ON_RES   	0xA4 // 关闭全屏显示
#define OLED_CMD_NORMAL_DISPLAY       	0xA6 // 正常显示模式
#define OLED_CMD_CHARGE_PUMP          	0x8D // 设置电荷泵
#define OLED_CMD_DISPLAY_ON           	0xAF // 打开显示
#define OLED_CMD_STOP_SCROLL          	0x2E // 停止滚动
#define OLED_CMD_START_SCROLL         	0x2F // 开始滚动
#define OLED_CMD_SET_SCROLL_AREA      	0xA3 // 设置滚动区域
#define OLED_CMD_SET_SCROLL_SPEED     	0x26 // 设置滚动速度
#define OLED_CMD_SET_SCROLL_DIRECTION 	0x27 // 设置滚动方向
#define OLED_CMD_SET_SCROLL_REGION    	0x29 // 设置滚动区域
#define OLED_CMD_SET_SCROLL_MODE      	0x2A // 设置滚动模式
#define OLED_CMD_SET_SCROLL_OFFSET    	0x2B // 设置滚动偏移量
#define OLED_CMD_SET_SCROLL_START     	0x2C // 设置滚动起始页
#define OLED_CMD_SET_SCROLL_END       	0x2D // 设置滚动结束页
#define OLED_CMD_SET_SCROLL_ACTIVATE  	0x2F // 激活滚动
#define OLED_CMD_SET_SCROLL_DEACTIVATE 	0x2E // 禁用滚动
#define OLED_CMD_SET_SCROLL_EXIT      	0x2E // 退出滚动
#define OLED_CMD_ENABLE_CHARGE_PUMP   	0x14 // 启用电荷泵
#define OLED_CMD_SET_CLOCK_DIV_VALUE  	0x80  // 设置时钟分频因子的值
#define OLED_CMD_SET_MULTIPLEX_VALUE  	0x3F  // 设置复用率的值
#define OLED_CMD_SET_DISP_OFFSET_VALUE 	0x00 // 设置显示偏移的值
#define OLED_CMD_SET_COM_PINS_VALUE    	0x12  // 设置COM引脚配置的值
#define OLED_CMD_SET_CONTRAST_VALUE   	0xCF  // 设置对比度的值
#define OLED_CMD_SET_PRECHARGE_VALUE  	0xF1  // 设置预充电周期的值
#define OLED_CMD_SET_VCOMH_VALUE      	0x40  // 设置VCOMH电平的值
#define OLED_CMD_SCROLL_DUMMY_BYTE    	0x00 // 虚拟字节
#define OLED_CMD_SCROLL_SPEED         	0x07 // 设置滚动速度
#define OLED_CMD_SCROLL_START_PAGE    	0x00 // 设置滚动起始页
#define OLED_CMD_SCROLL_END_PAGE      	0x07 // 设置滚动结束页
#define OLED_CMD_SCROLL_OFFSET        	0x01 // 垂直滚动偏移量
#define OLED_CMD_SCROLL_DUMMY_BYTE2   	0xFF // 虚拟字节

// I2C地址和内存地址宏定义
#define OLED_I2C_ADDRESS              0x78 // OLED显示屏的I2C地址
#define OLED_CMD_ADDRESS              0x00 // 命令寄存器地址
#define OLED_DATA_ADDRESS             0x40 // 数据寄存器地址
#define OLED_I2C_TIMEOUT              0x100 // I2C通信超时时间

// 初始化指令序列
uint8_t CMD_Data[] = {
    OLED_CMD_DISPLAY_OFF,            // 关闭显示，确保在初始化过程中显示屏不会意外显示内容
    OLED_CMD_SET_CLOCK_DIV,          // 设置时钟分频因子，用于调整显示时钟频率
    OLED_CMD_SET_CLOCK_DIV_VALUE,    // 设置时钟分频因子的具体值，通常为0x80
    OLED_CMD_SET_MULTIPLEX,          // 设置复用率，定义显示屏的行数
    OLED_CMD_SET_MULTIPLEX_VALUE,    // 设置复用率的具体值，通常为0x3F（1/64复用率）
    OLED_CMD_SET_DISP_OFFSET,        // 设置显示偏移量，用于调整显示内容的垂直位置
    OLED_CMD_SET_DISP_OFFSET_VALUE,  // 设置显示偏移量的具体值，通常为0x00（无偏移）
    OLED_CMD_SET_START_LINE,         // 设置起始行，定义数据写入的起始行地址
    OLED_CMD_SET_SEGMENT_REMAP,      // 设置段重映射，定义列地址的映射方式
    OLED_CMD_SET_COMSCAN_DEC,        // 设置COM扫描方向为递减，定义行扫描的方向
    OLED_CMD_SET_COM_PINS,           // 设置COM引脚配置，定义COM引脚的连接方式
    OLED_CMD_SET_COM_PINS_VALUE,     // 设置COM引脚配置的具体值，通常为0x12
    OLED_CMD_SET_CONTRAST,           // 设置对比度，定义显示内容的对比度
    OLED_CMD_SET_CONTRAST_VALUE,     // 设置对比度的具体值，通常为0xCF
    OLED_CMD_SET_PRECHARGE,          // 设置预充电周期，定义预充电的时间
    OLED_CMD_SET_PRECHARGE_VALUE,    // 设置预充电周期的具体值，通常为0xF1
    OLED_CMD_SET_VCOMH,              // 设置VCOMH电平，定义VCOMH的电压水平
    OLED_CMD_SET_VCOMH_VALUE,        // 设置VCOMH电平的具体值，通常为0x40
    OLED_CMD_DISPLAY_ALL_ON_RES,     // 关闭全屏显示，确保只有特定区域显示内容
    OLED_CMD_NORMAL_DISPLAY,         // 设置正常显示模式，关闭反向显示
    OLED_CMD_CHARGE_PUMP,            // 设置电荷泵，用于生成所需的电压
    OLED_CMD_ENABLE_CHARGE_PUMP,     // 启用电荷泵，确保显示屏能够正常工作
    OLED_CMD_DISPLAY_ON              // 打开显示，使显示屏开始显示内容
};

/**
 * 写入指令函数。
 * 通过I2C接口向OLED显示屏发送指令。
 *
 * @param cmd 要发送的指令
 */
void _OLED_Write_CMD(uint8_t cmd) {
    HAL_I2C_Mem_Write(&OLED_I2C, OLED_I2C_ADDRESS, OLED_CMD_ADDRESS, I2C_MEMADD_SIZE_8BIT, &cmd, 1, OLED_I2C_TIMEOUT);
}

/**
 * 写入数据函数。
 * 通过I2C接口向OLED显示屏发送数据。
 *
 * @param data 要发送的数据
 */
void _OLED_Write_DATA(uint8_t data) {
    HAL_I2C_Mem_Write(&OLED_I2C, OLED_I2C_ADDRESS, OLED_DATA_ADDRESS, I2C_MEMADD_SIZE_8BIT, &data, 1, OLED_I2C_TIMEOUT);
}

/**
 * 打开显示。
 * 启用电荷泵并打开OLED显示屏。
 */
void _OLED_Display_On(void) {
    _OLED_Write_CMD(OLED_CMD_CHARGE_PUMP);
    _OLED_Write_CMD(OLED_CMD_ENABLE_CHARGE_PUMP);
    _OLED_Write_CMD(OLED_CMD_DISPLAY_ON);
}

/**
 * 关闭显示。
 * 关闭电荷泵并关闭OLED显示屏。
 */
void _OLED_Display_Off(void) {
    _OLED_Write_CMD(OLED_CMD_CHARGE_PUMP);
    _OLED_Write_CMD(OLED_CMD_ENABLE_CHARGE_PUMP);
    _OLED_Write_CMD(OLED_CMD_DISPLAY_OFF);
}

/**
 * 设置光标位置。
 * 设置OLED显示屏的光标位置。
 *
 * @param x 水平位置
 * @param y 垂直位置
 */
void _OLED_Set_Pos(uint8_t x, uint8_t y) {
    _OLED_Write_CMD(0xb0 + y);       // 设置页地址
    _OLED_Write_CMD(((x & 0xf0) >> 4) | 0x10); // 设置列地址高4位
    _OLED_Write_CMD(x & 0x0f);       // 设置列地址低4位
}

/**
 * 填充屏幕。
 * 填充OLED显示屏的整个屏幕。
 */
void _OLED_On(void) {
    uint8_t i, n;
    for (i = 0; i < 8; i++) {
        _OLED_Write_CMD(0xb0 + i);   // 设置页地址
        _OLED_Write_CMD(0x00);       // 设置列地址低4位
        _OLED_Write_CMD(0x10);       // 设置列地址高4位
        for (n = 0; n < 128; n++) {
            _OLED_Write_DATA(1);     // 填充数据
        }
    }
}

/**
 * 初始化OLED显示屏。
 * 发送初始化指令序列以配置OLED显示屏。
 */
void OLED_Init(void) {
    uint8_t i = 0;
    for (i = 0; i < 23; i++) {
        _OLED_Write_CMD(CMD_Data[i]); // 发送初始化指令
    }
}

/**
 * 清屏函数。
 * 清除OLED显示屏的内容。
 */
void OLED_Clear(void) {
    uint8_t i, n;
    for (i = 0; i < 8; i++) {
        _OLED_Write_CMD(0xb0 + i);   // 设置页地址
        _OLED_Write_CMD(0x00);       // 设置列地址低4位
        _OLED_Write_CMD(0x10);       // 设置列地址高4位
        for (n = 0; n < 128; n++) {
            _OLED_Write_DATA(0);     // 填充数据
        }
    }
}

/**
 * 计算幂函数。
 * 计算 m 的 n 次幂。
 *
 * @param m 底数
 * @param n 指数
 * @return 计算结果
 */
unsigned int oled_pow(uint8_t m, uint8_t n) {
    unsigned int result = 1;
    while (n--) result *= m;
    return result;
}

/**
 * 显示数字。
 * 在OLED显示屏上显示数字。
 *
 * @param x 水平位置
 * @param y 垂直位置
 * @param num 要显示的数字
 * @param len 数字的长度
 * @param size2 字体大小
 * @param Color_Turn 颜色模式
 */
void OLED_ShowNum(uint8_t x, uint8_t y, unsigned int num, uint8_t len, uint8_t size2, uint8_t Color_Turn) {
    uint8_t t, temp;
    uint8_t enshow = 0;
    for (t = 0; t < len; t++) {
        temp = (num / oled_pow(10, len - t - 1)) % 10;
        if (enshow == 0 && t < (len - 1)) {
            if (temp == 0) {
                OLED_ShowChar(x + (size2) * t, y, ' ', size2, Color_Turn);
                continue;
            } else enshow = 1;
        }
        OLED_ShowChar(x + (size2) * t, y, temp + '0', size2, Color_Turn);
    }
}
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

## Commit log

2025-09-19 首次提交
2025-09-24 完成USB3.0输入原理图
    [ChinoHub.kicad_pcb, ChinoHub.kicad_sch, TypeC3.0Handle.kicad_sch]
2025-09-26 完成对系统框图的绘制
2025-09-26 完成TypeC转HDMI部分
    [ChinoHub.kicad_sch, TypeC2HDMI.kicad_sch]
2025-09-26 临时测试
2025-09-29 完成HUB部分原理图绘制
    [ChinoHub.kicad_sch, Power.kicad_sch, TypeC2HDMI.kicad_sch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]
2025-09-29 完成HUB部分基础内容
    [ChinoHub.kicad_sch, HDMI_OUT.kicad_sch, MCU.kicad_sch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]
2025-09-29 增加基础的STM32代码
    [HDMI_OUT.kicad_sch]
2025-10-03 完成除MCU外的设计
    [ChinoHub.kicad_pcb, ChinoHub.kicad_sch, HDMI_OUT.kicad_sch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]
2025-10-03 修改了电源供电部分的内容
    [HDMI_OUT.kicad_sch, Power.kicad_sch]
2025-10-04 complete sch
    [ChinoHub.kicad_sch, HDMI_OUT.kicad_sch, MCU.kicad_sch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]
2025-10-04 修改了一些小错误,并补充部分外设
    [ChinoHub.kicad_pcb, MCU.kicad_sch]
2025-10-05 开始PCB布局
    [ChinoHub.kicad_pcb, Power.kicad_sch, TypeC3.0Handle.kicad_sch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]

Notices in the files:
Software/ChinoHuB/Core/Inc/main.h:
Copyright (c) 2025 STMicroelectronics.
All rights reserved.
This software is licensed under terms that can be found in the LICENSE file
